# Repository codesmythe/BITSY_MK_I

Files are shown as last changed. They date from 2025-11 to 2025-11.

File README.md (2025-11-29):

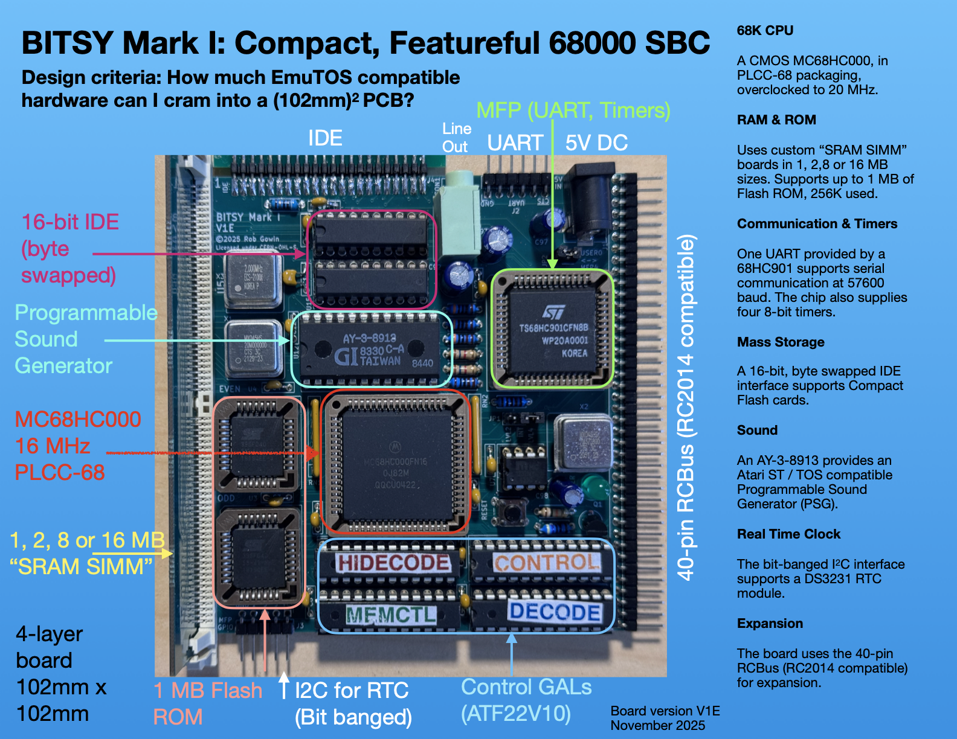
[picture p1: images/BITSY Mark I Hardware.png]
BITSY


This board is designed to run the [EmuTOS](https://emutos.sourceforge.io) operating system. EmuTOS is an open-source variant of the Atari ST TOS operating system.

BITSY Mark I is part of system containing this board, a [XOSERA_RCBUS](https://github.com/codesmythe/XOSERA_RCBUS) board for VGA output, a [KEMOJO](https://github.com/codesmythe/KEMOJO) board for
PS/2 keyboard and mouse input, and an RCBus backplane board such as an [SC147](https://smallcomputercentral.com/rcbus/sc100-series/sc147-modular-backplane-rc2014/). Together, this system can run full GUI EmuTOS with 640x240 graphics in 16 colors.

This SBC can also be used by itself, in EmuTOS command-line mode, using the on-board UART for serial input and output at 57600 baud.

But please do note that it is early days for this system, so there are undiscovered bugs looming. In particular, you may see occasional graphical artifacts in EmuTOS as the driver is debugged.

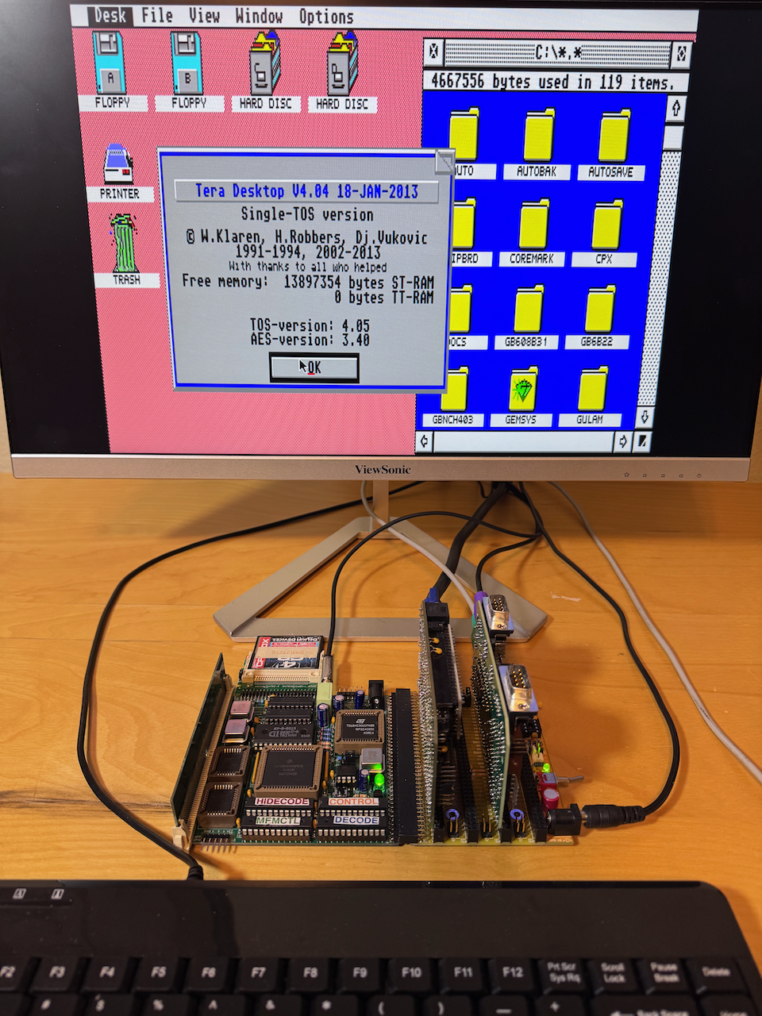
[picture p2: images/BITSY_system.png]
BITSY System
|                      |
| :----------------------------------------------------------: |
| Full BITSY system running [Teradesk](https://github.com/freemint/teradesk) with color icons on EmuTOS. Free memory shows 16 MB SRAM SIMM in use. |

## Table of Contents
* [Hardware Documentation](#hardware-documentation)
  * [Schematic](#schematic)
  * [Connectors](#connectors)
  * [Jumpers](#jumpers)
  * [SRAM Choice](#sram-choice)
  * [Bill of Materials](#bill-of-materials)
* [Firmware Documentation](#firmware-documentation)
   * [ROM: EmuTOS](#rom-emutos)
   * [SPLD Fuse Maps](#spld-fuse-maps)

## Hardware Documentation

### Schematics

This four layer, 102mm x 102mm board was created using [Kicad](https://www.kicad.org) version 8.0. The KiCad files are
available in this repository.

The image below shows the top level schematic page. Click on it to download the full eight page schematic in PDF format.

Schematic

### Connectors

| Reference | Description |
| --- | --- |
| J1 | Barrel jack connection for a 2A, 5V, 2mm power supply. |
| J2 | Six pin male header for connection to a USB-to-serial adapters. Uses the [FTDI Friend](https://www.adafruit.com/product/284) pinout. |
| J3 | Five pin male header for connection to a DS3231 Real Time Clock module. |
| J5 | 40-pin connection to an RCBus 40-pin or 80-pin backplane. |

### Jumpers

| Refence | Picture | Description | Comment |
| --- | --- | --- | --- |
| JP1 | | Connects RCBus /INT (pin 22) to 68K interrupt level 4 (1-2) or level 2 (2-3) | When using BITSY Mark I with the [XOSERA_RCBUS](https://github.com/codesmythe/XOSERA_RCBUS) board, jumper pins 1-2 to use 68K /INT4. |
| JP2 | | When closed, connects RCBus USER1/INT1 (pin 37) to MFP GPIO4. When open, RCBus pin 37 is unconnected. | Close this jumper when using the [KEMOJO](https://github.com/codesmythe/KEMOJO) board for PS/2 keyboard, PS/2 mouse and joystick support. |

### SRAM Choice

Memory for this board is hosted on a custom 72-pin "SRAM SIMM" board. Though SIMMs are conventionally associated with DRAMs, these custom modules present a static RAM (SRAM) interface to the motherboard. Thus they have a demultiplexed address bus and use SRAM control signals such as chip enable, output enable and write enables.

> [!WARNING]
> BITSY_MK_I is **completely incompatible** with conventional DRAM SIMMs.

#### 1 MB SRAM SIMM

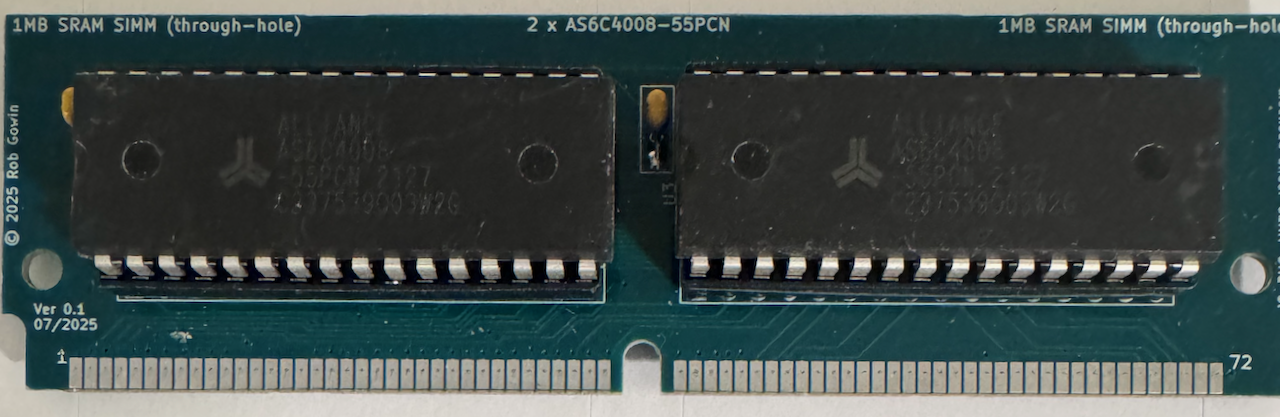
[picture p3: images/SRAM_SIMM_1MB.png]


The 1 MB through hole version is a good choice to start with, as it is inexpensive and easy to solder. Gerbers for the boards are available in this repository. So if you
are ordering a BITSY board from a PCB maker, also order one of these memory modules.

#### 16 MB SRAM SIMM

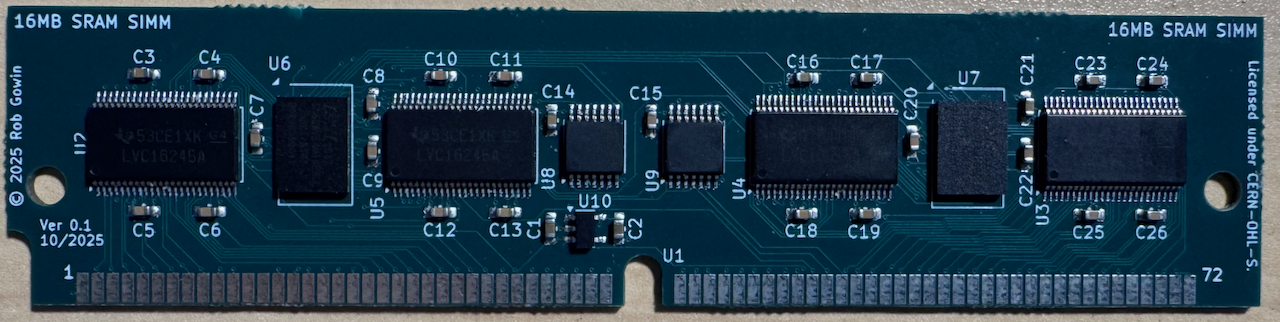
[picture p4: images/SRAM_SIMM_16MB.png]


If you end up using the system regularly, I'd suggest upgrading to a 16 MB "SRAM SIMM" I have created. If interested, please contact me about purchasing a 16 MB module, which run about USD $36 each. Alternatively, you can have JLCPCB assemble them yourself using the design files in [this](http://github.com/codesmythe/SRAM_SIMM_16MB) repository.

### Bill of Materials

[Text file parts list](BITSY_V1E_mouser.txt) for pasting into the [Mouser BOM tool](https://www.mouser.com/Bom/CopyPaste) (login required).

To obtain a BITSY Mark I PCB, download these [Gerbers](https://github.com/codesmythe/BITSY_MK_I/raw/refs/heads/main/BITSY_Mark_I_V1E.zip) for use at your preferred PCB manufacturer. I use JLCPCB.

| Component Type | Reference | Qty  | Description | Part |
| --- | --- | ---- | --- | --- |
| CF Adapter | none | 1 | Compact Flash Male IDE 44pin adapter | eBay or Amazon: search for "Compact Flash Male IDE 44pin adapter" |
| RTC | none | 1 | (optional) DS3231 I2C Real Time Clock module | Amazon: search for "DS3231 rtc module". Get a black one with 5-pin female connector and yellow battery. |
| Capacitor | C1-C4,C7-C12,C14,C15 | 12 | 0.1 uF, MLCC, 5 mm Pitch | Mouser [594-K104K15X7RF5TH5](https://www.mouser.com/ProductDetail/594-K104K15X7RF5TH5) |
| Capacitor | C92,C93 | 2 | Electrolytic Capacitor, Radial, 6.3V 470uF, 6.3D, 2.5P | Mouser [80-ESK477M6R3AE3AA](https://www.mouser.com/ProductDetail/80-ESK477M6R3AE3AA) |
| Capacitor | C94 | 1 | MLCC, Leaded 100pF 50V 5% C0G 5mm | Mouser [594-K101J15C0GF5TH5](https://www.mouser.com/ProductDetail/594-K101J15C0GF5TH5) |
| Capacitor | C97,C98 | 2 | Electrolytic Capacitor, Radial, 16V, 100uF, 5D, 2.5P | Mouser [667-ECA-1CM101I](https://www.mouser.com/ProductDetail/667-ECA-1CM101I) |
| Capacitor | CON1 | 1 | Audio Jack, 3 Poles, Switched TR Poles | Mouser [490-SJ1-3535NG](https://www.mouser.com/ProductDetail/490-SJ1-3535NG) |
| Diode | D1 | 1 | Green LED, through hole, 5 mm pitch | Mouser [859-LTL-307GLC](https://www.mouser.com/ProductDetail/859-LTL-307GLC) |
| Jumper | J1 | 1 | DC Barrel Jack | Mouser [490-PJ-002A](https://www.mouser.com/ProductDetail/490-PJ-002A) |
| Jumper | J2 | 1 | 1x6 right angle pin header | Mouser [737-PH1RB-06-UA](https://www.mouser.com/ProductDetail/737-PH1RB-06-UA) |
| Jumper | J3 | 1 | 1x5 right angle pin header | Mouser [737-PH1RB-05-UA](https://www.mouser.com/ProductDetail/737-PH1RB-05-UA) |
| Jumper | J5 | 1 | 1x40 right angle pin header | Mouser [710-61304011021](https://www.mouser.com/ProductDetail/710-61304011021) |
| Jumper | JP1 | 1 | 1x3 straight pin header | Mouser [200-TSW10307TS](https://www.mouser.com/ProductDetail/200-TSW10307TS) |
| Jumper | JP2 | 1 | 1x2 straight pin header | Mouser [200-TSW10207TS](https://www.mouser.com/ProductDetail/200-TSW10207TS) |
| Transistor | Q1 | 1 | 2N7000  MOSFET in TO92 | Mouser [512-2N7000](https://www.mouser.com/ProductDetail/512-2N7000) |
| Resistor | R2 | 1 | 470 ohm, axial, 1% tolerance, 1/4 W | Mouser [603-MFR-25FTE52-470R](https://www.mouser.com/ProductDetail/603-MFR-25FTE52-470R) |
| Resistor | R3 | 1 | 10K ohm, axial, 1% tolerance, 1/4 W | Mouser [603-MFR-25FTE52-10K](https://www.mouser.com/ProductDetail/603-MFR-25FTE52-10K) |
| Resistor | R84,R85 | 2 | 1K ohm, axial, 1% tolerance, 1/4 W | Mouser [603-MFR-25FTE52-1K](https://www.mouser.com/ProductDetail/603-MFR-25FTE52-1K) |
| Resistor | R86,R87 | 2 | 1600 ohm, axial, 1% tolerance, 1/4 W | Mouser [603-MFR-25FTE52-1K6](https://www.mouser.com/ProductDetail/603-MFR-25FTE52-1K6) |
| Resistor | R88-R90 | 3 | 3K ohm, axial, 1% tolerance, 1/4 W | Mouser [603-MFR-25FTE52-3K](https://www.mouser.com/ProductDetail/603-MFR-25FTE52-3K) |
| Resistor | R97 | 1 | 100 ohm, axial, 1% tolerance, 1/4 W | Mouser [603-MFR-25FBF52-100R](https://www.mouser.com/ProductDetail/603-MFR-25FBF52-100R) |
| Resistor | RN1,RN2 | 2 | 4.7K ohm bussed network, 6 resistors, 7 pins, SIP | Mouser [652-4607X-1LF-4.7K](https://www.mouser.com/ProductDetail/652-4607X-1LF-4.7K) |
| Switch | SW1 | 1 | Push button switch | Mouser [179-TS026655BK160LCR](https://www.mouser.com/ProductDetail/179-TS026655BK160LCR) |
| Integrated Circuit | U1 | 1 | MC68HC000 CPU in PLCC-68, 20 MHz | Ebay: search for "MC68HC000FN20" |
| Integrated Circuit | U2 | 1 | TS68HC901 Multi Function Peripheral (MFP) chip in PLCC-52 | Ebay: search for "TS68HC901CFN8B" |
| Integrated Circuit | U3,U4 | 2 | 512k x 8 Flash ROM in PLCC-32 | Mouser [579-39SF040554CNHET](https://www.mouser.com/ProductDetail/579-39SF040554CNHET) |
| Integrated Circuit | U7 | 1 | MIC1232 CPU Supervisor in 8-pin DIP | Mouser [998-MIC1232NY](https://www.mouser.com/ProductDetail/998-MIC1232NY) |
| Integrated Circuit | U8-U11 | 4 | ATF22V10C-15PU, Simple PLD, 24 I/O in 24-pin DIP | Mouser [556-AF22V10C15PU](https://www.mouser.com/ProductDetail/556-AF22V10C15PU) |
| Integrated Circuit | U12 | 1 | AY-3-8913 Programmable Sound Generator (PSG) in 24-pin wide DIP | Ebay: search for "AY-3-8913" |
| Integrated Circuit | U14,U15 | 2 | 74HCT245 Octal Bus Transceivers in 20-pin DIP | Mouser [595-SN74HCT245N](https://www.mouser.com/ProductDetail/595-SN74HCT245N) |
| Oscillator | X1 | 1 | 16 MHz can oscillator in 8-pin DIP | Mouser [774-MXO45HST-3C-16.0](https://www.mouser.com/ProductDetail/774-MXO45HST-3C-16.0) |
| Oscillator | X2 | 1 | 7.3278 MHz can oscillator in 8-pin DIP | Mouser [774-MXO45HS-3C-7.3](https://www.mouser.com/ProductDetail/774-MXO45HS-3C-7.3) |
| Oscillator | X3 | 1 | 2 MHz can oscillator in 8-pin DIP | Mouser [774-MXO45HS2C2M0000](https://www.mouser.com/ProductDetail/774-MXO45HS2C2M0000) |
| Socket | Socket for U1 | 1 | 68-pin PLCC socket | Mouser [575-682444](https://www.mouser.com/ProductDetail/575-682444) |
| Socket | Socket for U2 | 1 | 52-pin PLCC socket | Mouser [575-945224](https://www.mouser.com/ProductDetail/575-945224) |
| Socket | Socket for U3,U4 | 2 | 32-pin PLCC socket | Mouser [649-54020-32030LF](https://www.mouser.com/ProductDetail/649-54020-32030LF) |
| Socket | Socket U5 | 1 | SIMM Connectors 72 POS SIMM VERT TIN | Mouser [571-5822021-4](https://www.mouser.com/ProductDetail/571-5822021-4) |
| Socket | Socket for U7 | 1 | 8-pin DIP socket | Mouser [737-ICM-308-1-GT-HT](https://www.mouser.com/ProductDetail/737-ICM-308-1-GT-HT) |
| Socket | Socket for U8-U11 | 4 | 24-pin DIP socket | Mouser [737-ICM-324-1-GT-HT](https://www.mouser.com/ProductDetail/737-ICM-324-1-GT-HT) |
| Socket | Socket for U12 | 1 | 24-pin wide DIP socket | Mouser [737-ICM-624-1-GT-HT](https://www.mouser.com/ProductDetail/737-ICM-624-1-GT-HT) |
| Socket | Socket for U14,U15 | 2 | 20-pin DIP socket | Mouser [737-ICM-320-1-GT-HT](https://www.mouser.com/ProductDetail/737-ICM-320-1-GT-HT) |
| Socket | Socket for X1-X3 | 3 | 8-pin oscillator socket | Mouser [535-1108800](https://www.mouser.com/ProductDetail/535-1108800) |

## Firmware Documentation

### ROM: EmuTOS

As mentioned, this board is designed to run EmuTOS. The source code for my fork of EmuTOS to support various 68K single
board computers, including this one, can be found [here](https://github.com/codesmythe/emutos). The version of EmuTOS in the fork is
based on EmuTOS version 1.4.

Two default configurations are provided by the ROM binaries in this repository. Other configurations are
available by compiling EmuTOS from the source code linked above.

#### Configuration: Using serial port command line I/O interface

The first configuraiton uses the UART provided by the MC68901 and runs EmuTOS in "serial console" mode. 
In this configuration, 1 MB of SRAM is supported, which can be provided using two standard 512K 32-pin DIP SRAMs 
like the AS6C4008 mounted on an "SRAM SIMIM" adapter mentioned above. The "EmuCON" part of EmuTOS provides a command line interface. Here are the even and odd ROM binaries for this configuration:

| ROM  | Size | File | 
| ---- | --- | ---- |
| Even | 512KB  | [bitsy_v1_sercon_1mb_20251123.even.bin](https://github.com/codesmythe/BITSY_MK_I/raw/refs/heads/main/ROMS/bitsy_v1_sercon_1mb_20251123.even.bin) | 
| Odd  | 512KB  | [bitsy_v1_sercon_1mb_20251123.odd.bin](https://github.com/codesmythe/BITSY_MK_I/raw/refs/heads/main/ROMS/bitsy_v1_sercon_1mb_20251123.odd.bin) | 

#### Configuration: Using VGA and PS/2 support to run EmuTOS GUI (GEM)

The second configuration runs EmuTOS in full GUI (GEM) mode and requires the use of the 
[XOSERA_RCBUS](https://github.com/codesmythe/XOSERA_RCBUS) and [KEMOJO](https://github.com/codesmythe/KEMOJO) boards to provide VGA output and PS/2 keyboard and mouse input. In this configuration, at least 4MB is suggested so I recommend using the 16 MB "SRAM SIMM" module described above. It is possible to run GEM mode in 1 MB of RAM, but for you now you will have configure EmuTOS and compile it from source. Here are the even and odd ROM binaries for the 14 MB configuration:

| ROM  | Size | File | 
| ---- | --- | ---- |
| Even | 512KB  | [bitsy_v1_gem_14mb_20251123.even.bin](https://github.com/codesmythe/BITSY_MK_I/raw/refs/heads/main/ROMS/bitsy_v1_gem_14mb_20251123.even.bin) |
| Odd  | 512KB  | [bitsy_v1_gem_14mb_20251123.odd.bin](https://github.com/codesmythe/BITSY_MK_I/raw/refs/heads/main/ROMS/bitsy_v1_gem_14mb_20251123.odd.bin) |

#### Memory Map

| Address Range | Use  |
| ---|---|
| 00_0000 to (0F_FFFF or DF_FFFF) | 1 MB or 14 MB RAM |
| E0_0000 to EF_FFFF | 1 MB ROM |
| F0_0000 to F0_003F | IDE (mirrored every 64 bytes in the 4K byte range from F0_0000 to F0_0FFF.) |
| FF_0000 to FF_FFFF | 64K RC2014 IO (IOREQ). Includes the on-board PSG and MFP. |

#### I/O Map

These addresses (and the IDE addresses above) are the same as the Atari ST for software compatibility.

| Address Range | Use | 
|---|---|
| FF_FA01 to FF_FA2F | MFP (odd byte lane) mirrored every 48 bytes in the 256 byte range from FF_FA00 to FA_FAFF.) |
| FF_8800 to FF_8803 | PSG (even byte lane) mirrored every  4 bytes in the 256 byte range from FF_8800 to FF_88FF.) | 
| FF_0191 to FF_01A1 | TL16C550 UART on KEMOJO board (odd byte lane), if using default setting of 0xC8 on that board. |
| FF_81c1 to FF_81E1 | Xosera registers, if using default setting of 0xE0 on that board. |

### SPLD Fuse Maps

BITSY Mark I uses four ATF22V10/GAL22V10 SPLDs (U8 - U11) for address decode and various other control logic. The SPLD fuse maps (JED files) can be downloaded via the links in the table below. The SPLDs are implemented using Flash/EEPROM technology and can be programmed by commonly available EPROM programmers, such as MiniPro TL866 II+ or newer. The source code (PLD) files  are also provided in the repository. If needed, they can be modified. Use [GALasm](https://github.com/daveho/GALasm)  to compile PLD files to JED fuse maps.

Note that there are separate fuse files for U9/HIDECODE depending on whether you are using 1 MB or 14 MB SRAM.

| Reference  | Source File | JED File | Functions |
| --- | --- | --- | --- |
| U8 | [MEMCTL.PLD](MEMCTL.PLD) | [MEMCTL.jed](https://github.com/codesmythe/BITSY_MK_I/raw/refs/heads/main/MEMCTL.jed) | Interrupt control, RCBus interface |
| U9 (1 MB)  | [HIDECODE.PLD](HIDECODE.PLD) | [HIDECODE.jed](https://github.com/codesmythe/BITSY_MK_I/raw/refs/heads/main/HIDECODE.jed) | Decode high part of address bus for 1 MB SRAM  |
| U9 (16 MB) | [HIDECODE_16MB.PLD](HIDECODE_16MB.PLD) | [HIDECODE_16MB.jed](https://github.com/codesmythe/BITSY_MK_I/raw/refs/heads/main/HIDECODE_16MB.jed) | Decode high part of address bus for 14 MB SRAM |
| U10 | [CONTROL.PLD](CONTROL.PLD) | [CONTROL.jed](https://github.com/codesmythe/BITSY_MK_I/raw/refs/heads/main/CONTROL.jed) | Wait states, DTACK generation, IDE interface |
| U11 | [DECODE.PLD](DECODE.PLD) | [DECODE.jed](https://github.com/codesmythe/BITSY_MK_I/raw/refs/heads/main/DECODE.jed) | Decode low part of address bus |

### Acknowledgements

When I designed this board, I took ideas and inspiration from these projects:

- Bill Shen's [Tiny68K](https://www.retrobrewcomputers.org/doku.php?id=boards:sbc:tiny68k) board.

- John Coffmans's [Mini-68K](https://www.retrobrewcomputers.org/doku.php?id=boards:ecb:mini-68k:start) ECB board.

- Clements, Alan. [*Microprocessor Systems Design: 68000 Hardware, Software and Interfacing, Third Edition*](https://archive.org/details/microprocessor-systems-design-alan-clements-9780534948221)
 PWS Publishing Company, 1997.

- [Atari ST schematics](https://archive.org/details/Atari_520ST_Schematic_1985/mode/1up)

- Various [Motorola Application Notes](http://www.bitsavers.org/components/motorola/_appNotes/) from back in the day.

The sound output circuit is borrowed from https://hw.speccy.cz/melodik2.html by way of https://github.com/electrified/rc2014-ym2149/blob/main/README.md

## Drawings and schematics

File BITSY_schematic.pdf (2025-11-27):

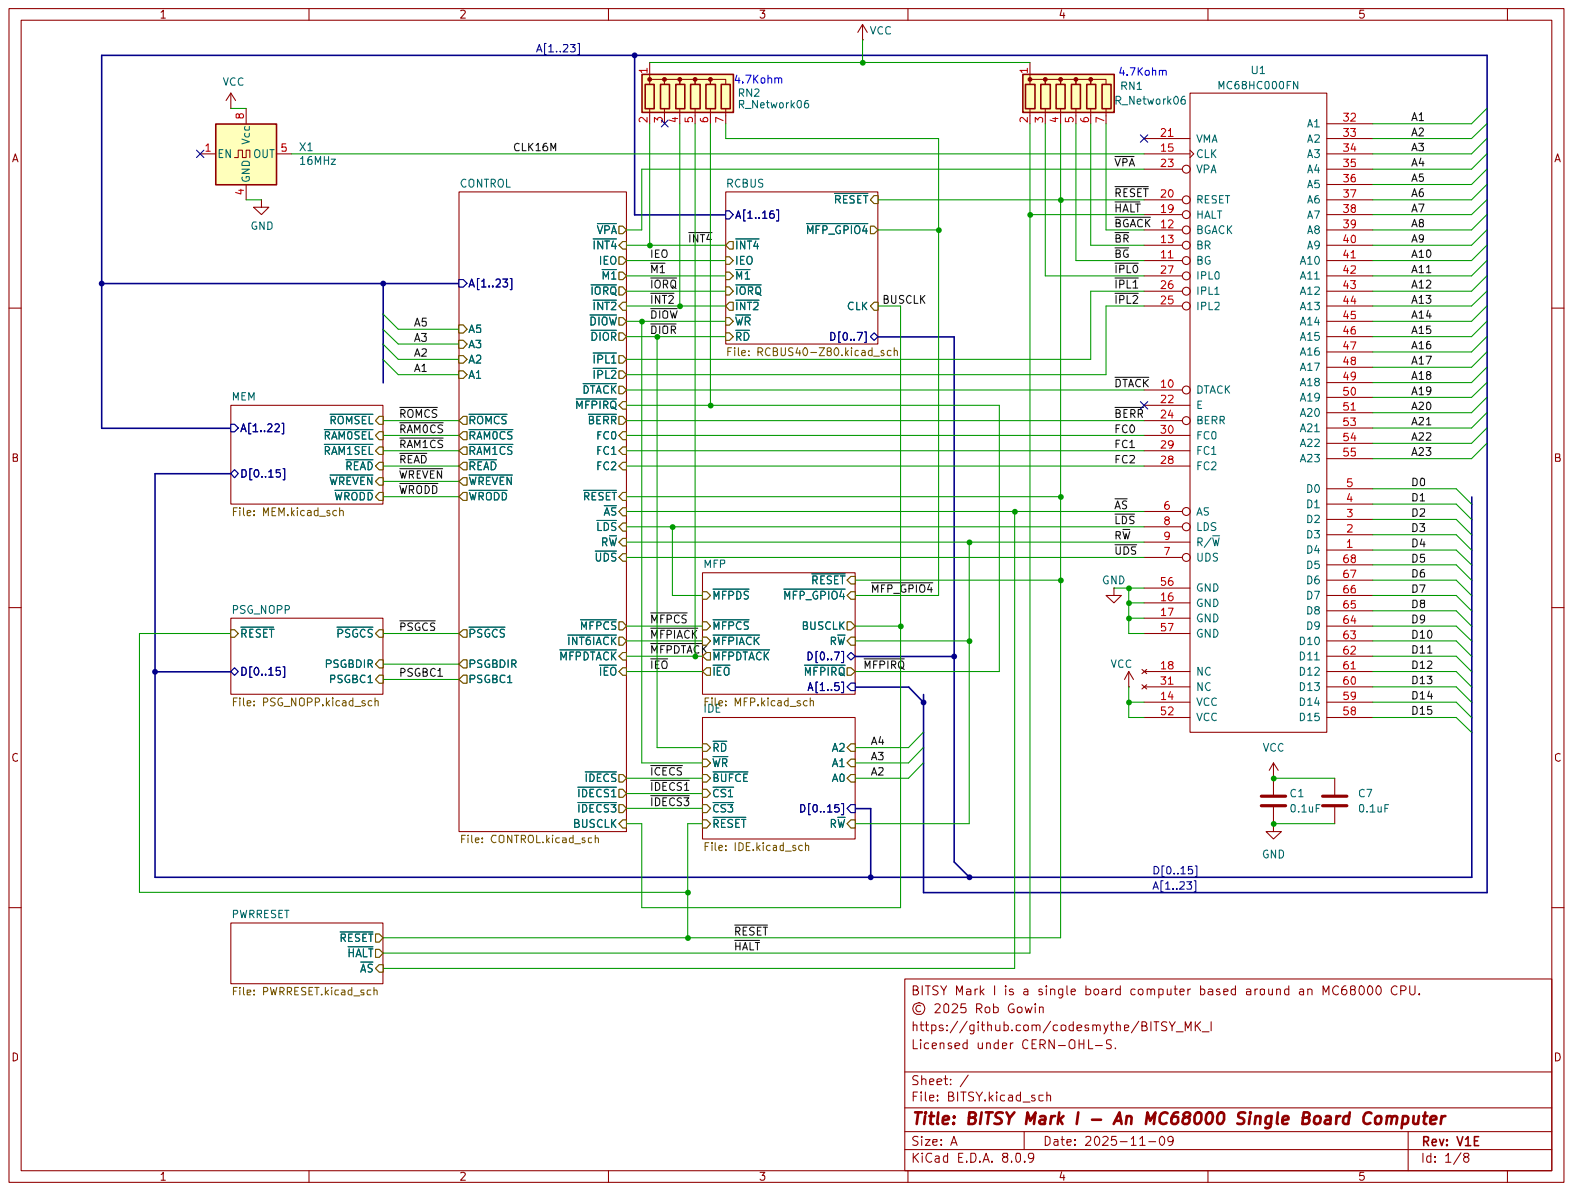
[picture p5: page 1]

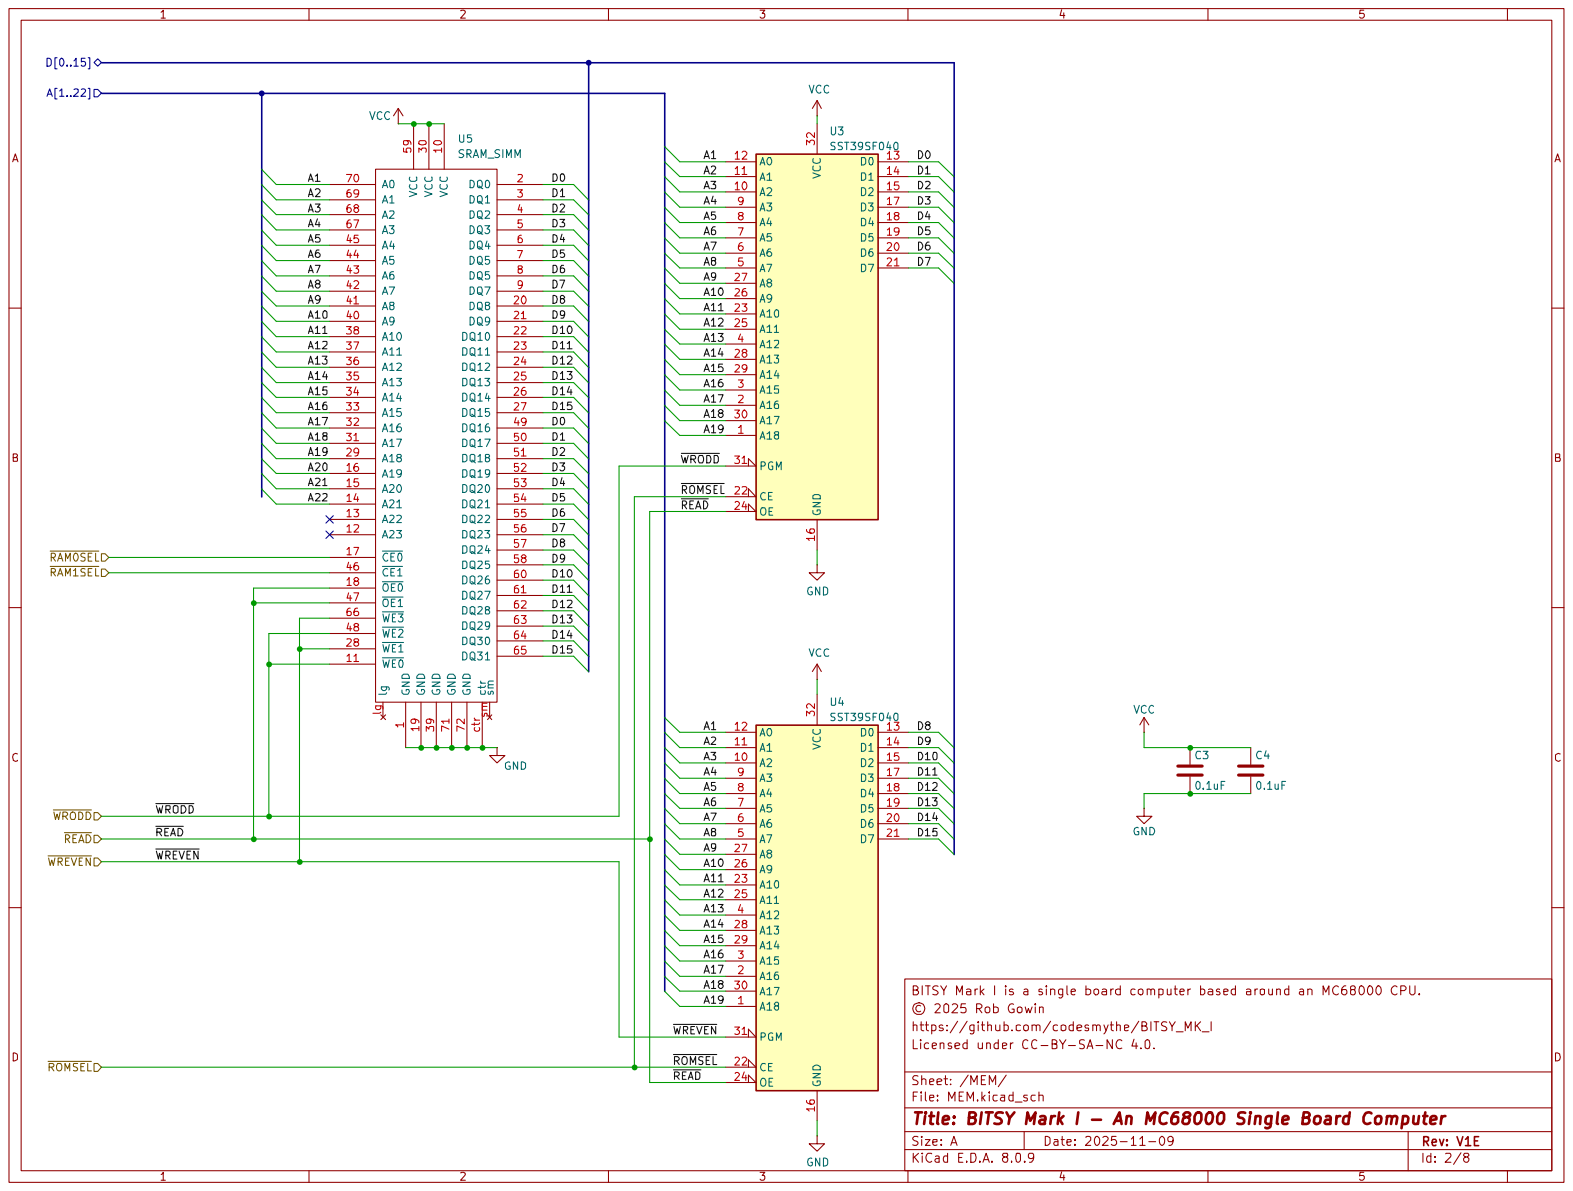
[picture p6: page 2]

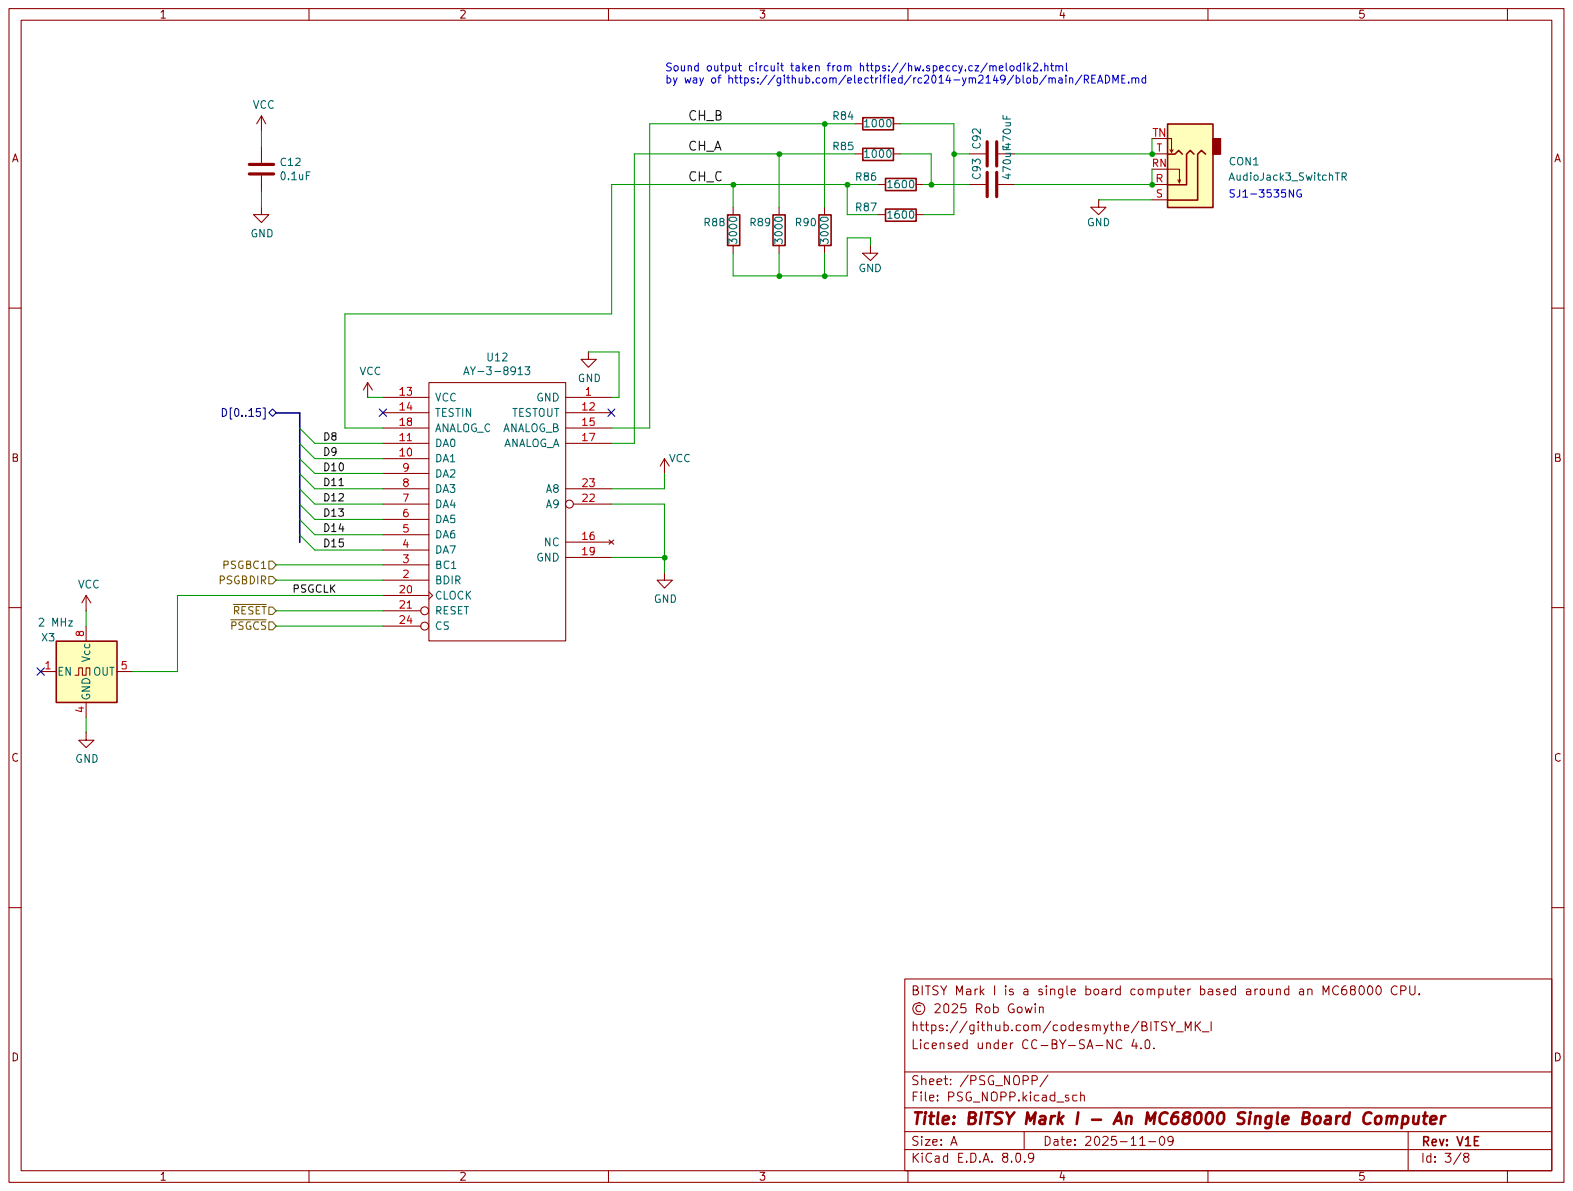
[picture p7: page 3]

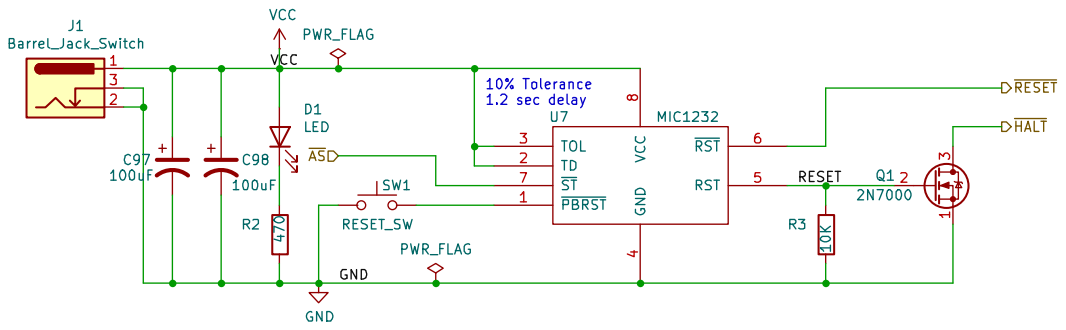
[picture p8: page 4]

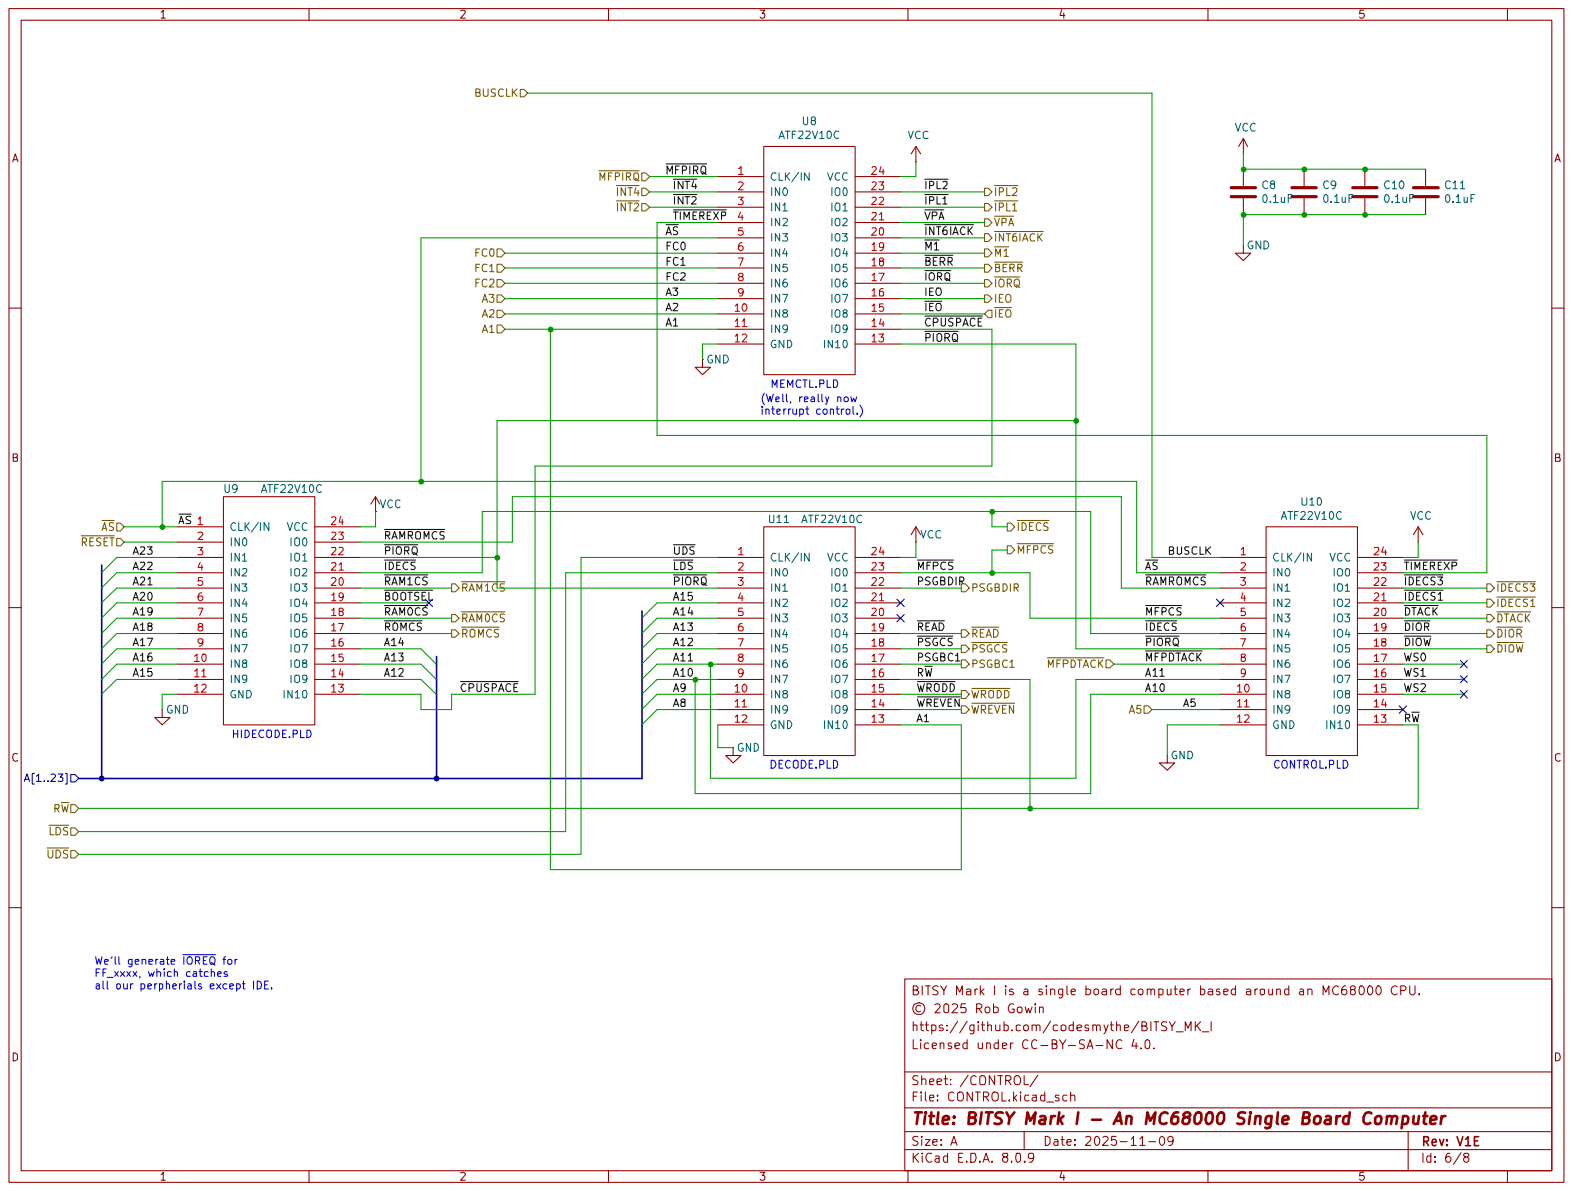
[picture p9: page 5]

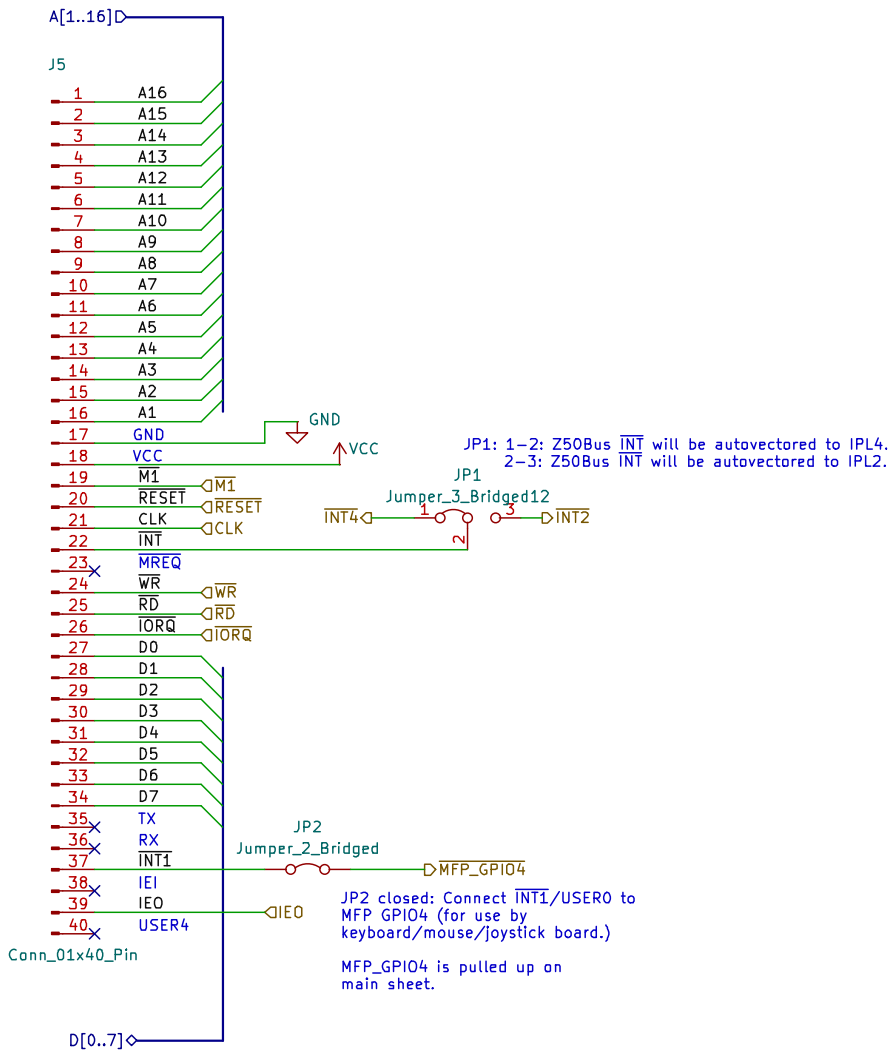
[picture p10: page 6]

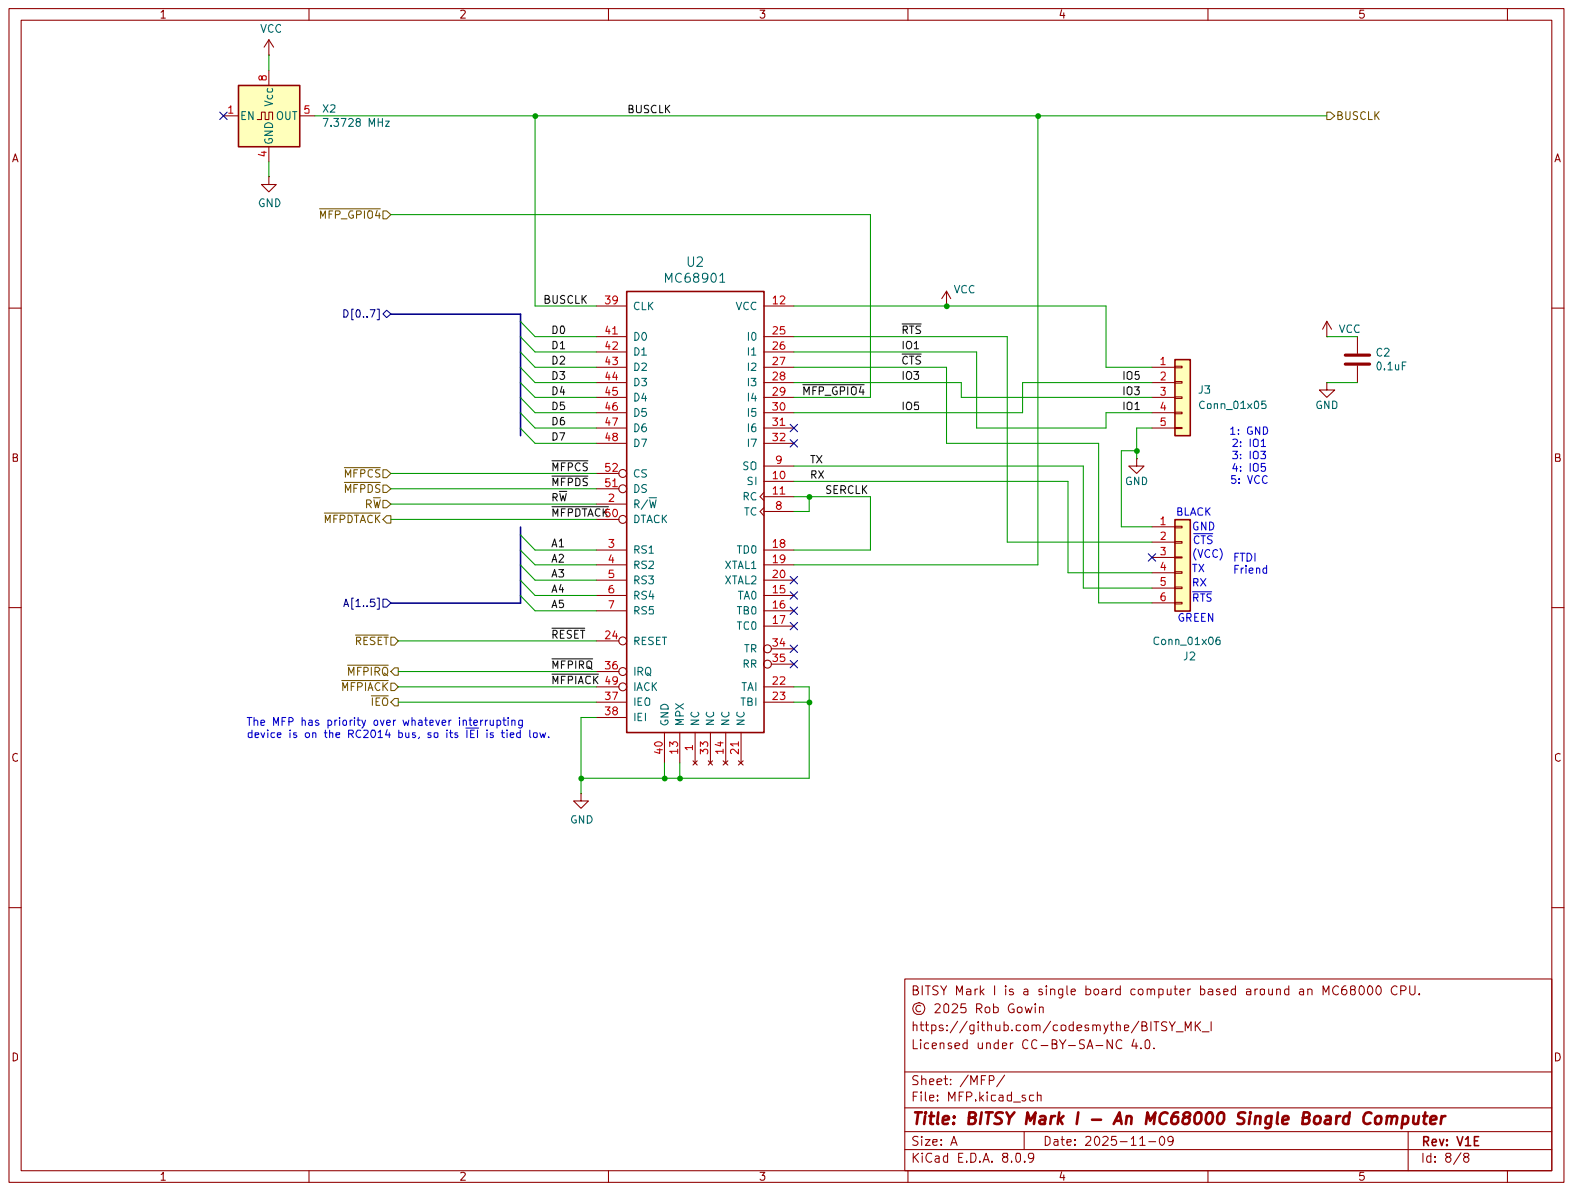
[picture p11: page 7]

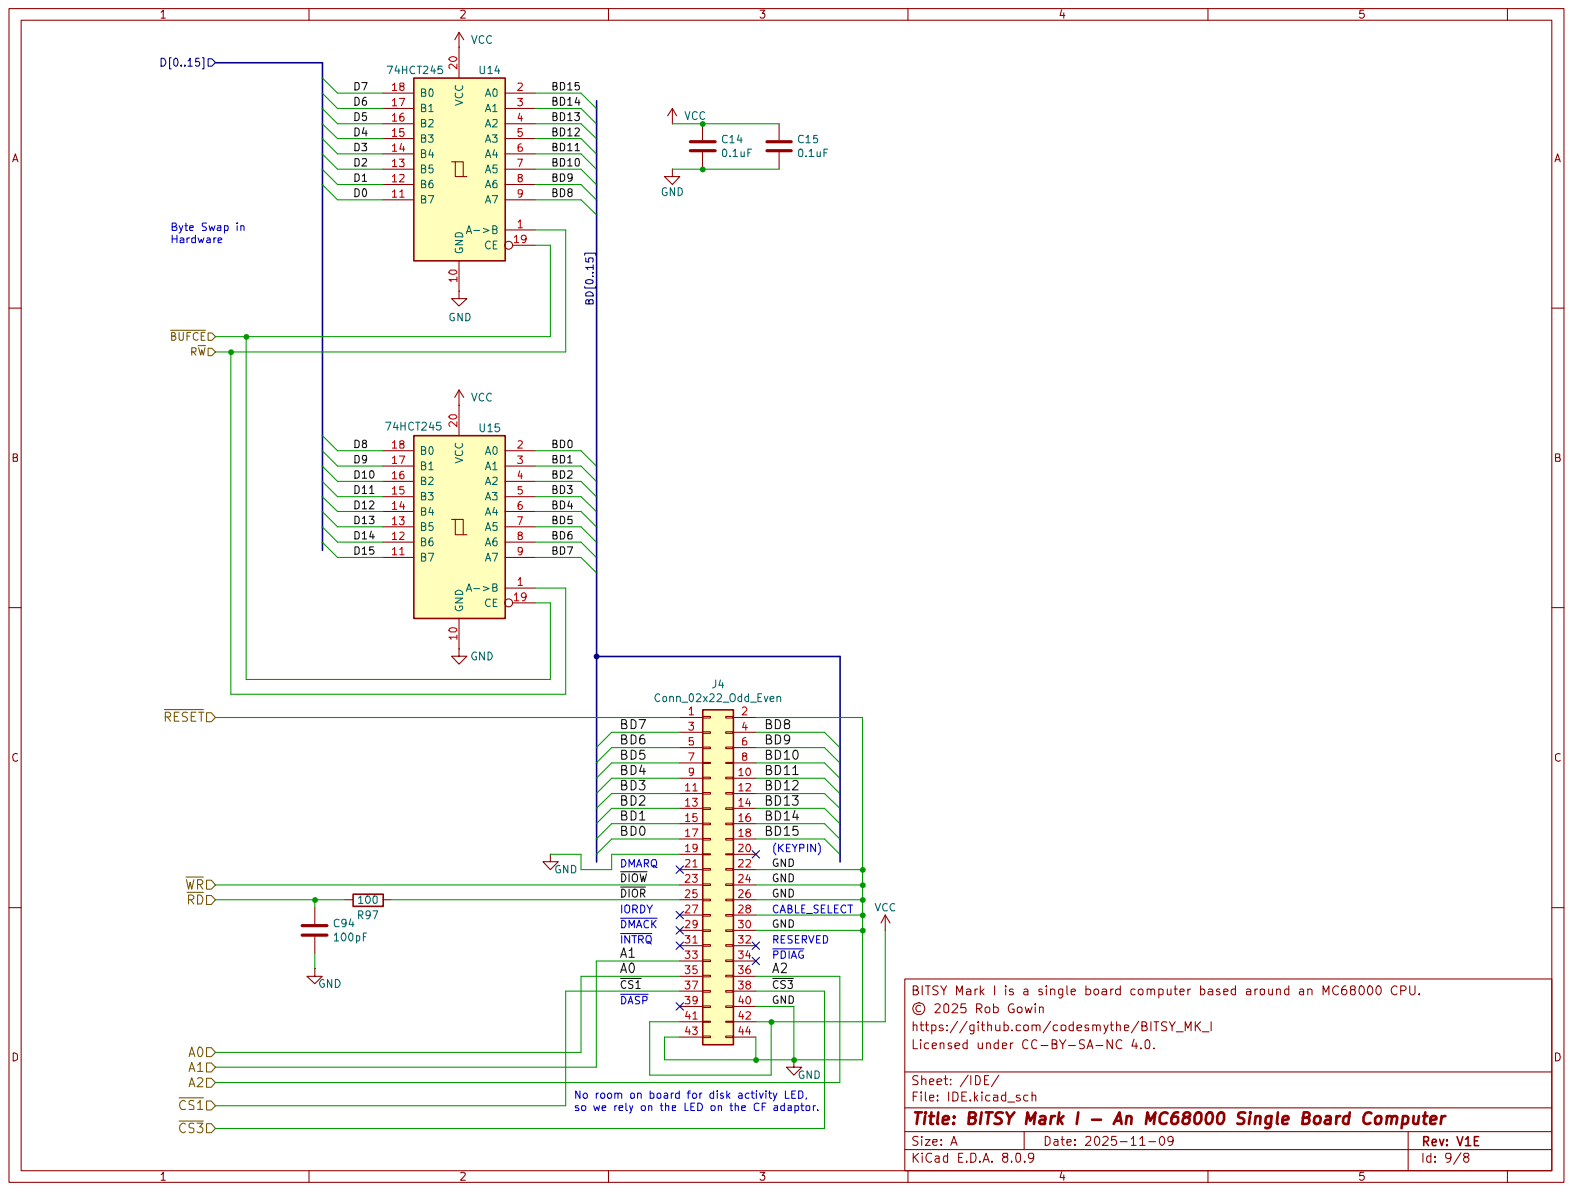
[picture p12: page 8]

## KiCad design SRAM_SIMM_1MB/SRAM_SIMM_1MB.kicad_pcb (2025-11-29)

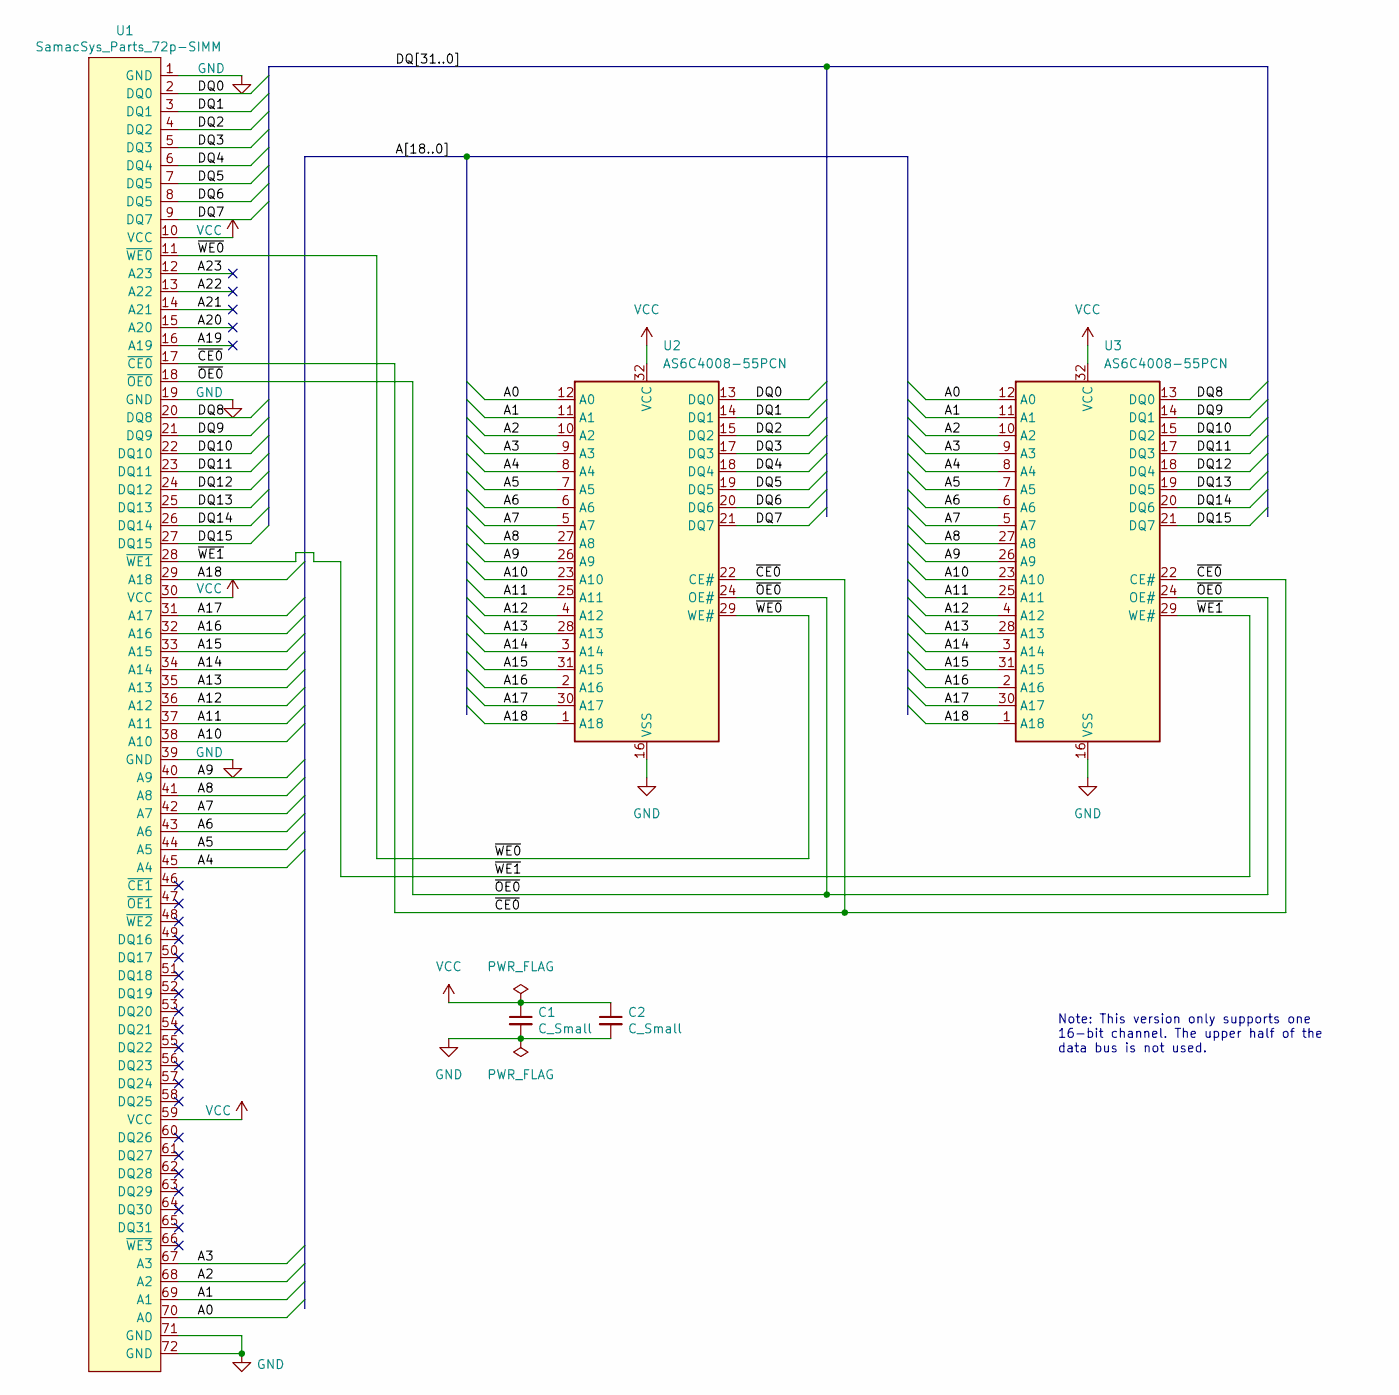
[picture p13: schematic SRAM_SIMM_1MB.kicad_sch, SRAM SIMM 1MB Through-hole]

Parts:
C1, C2: C_Small; C_Rect_L7.0mm_W2.5mm_P5.00mm; MouserPN 594-K104K15X7RF5TH5; LCSC C2167231
U1: SamacSys_Parts_72p-SIMM; 72p-SIMM; MouserPN 571-5822021-4; DigiKeyPN A114049-ND
U2, U3: AS6C4008-55PCN; DIP-32_W15.24mm_Socket_LongPads; MouserPN 913-AS6C4008-55PCN; LCSC C1350141

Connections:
/A0: U1.70 (A0), U2.12 (A0), U3.12 (A0)
/A1: U1.69 (A1), U2.11 (A1), U3.11 (A1)
/A2: U1.68 (A2), U2.10 (A2), U3.10 (A2)
/A3: U1.67 (A3), U2.9 (A3), U3.9 (A3)
/A4: U1.45 (A4), U2.8 (A4), U3.8 (A4)
/A5: U1.44 (A5), U2.7 (A5), U3.7 (A5)
/A6: U1.43 (A6), U2.6 (A6), U3.6 (A6)
/A7: U1.42 (A7), U2.5 (A7), U3.5 (A7)
/A8: U1.41 (A8), U2.27 (A8), U3.27 (A8)
/A9: U1.40 (A9), U2.26 (A9), U3.26 (A9)
/A10: U1.38 (A10), U2.23 (A10), U3.23 (A10)
/A11: U1.37 (A11), U2.25 (A11), U3.25 (A11)
/A12: U1.36 (A12), U2.4 (A12), U3.4 (A12)
/A13: U1.35 (A13), U2.28 (A13), U3.28 (A13)
/A14: U1.34 (A14), U2.3 (A14), U3.3 (A14)
/A15: U1.33 (A15), U2.31 (A15), U3.31 (A15)
/A16: U1.32 (A16), U2.2 (A16), U3.2 (A16)
/A17: U1.31 (A17), U2.30 (A17), U3.30 (A17)
/A18: U1.29 (A18), U2.1 (A18), U3.1 (A18)
/A19: U1.16 (A19)
/A19_1: U1.16 (A19)
/A20: U1.15 (A20)
/A20_1: U1.15 (A20)
/A21: U1.14 (A21)
/A21_1: U1.14 (A21)
/A22: U1.13 (A22)
/A22_1: U1.13 (A22)
/A23: U1.12 (A23)
/A23_1: U1.12 (A23)
/DQ0: U1.2 (DQ0), U2.13 (DQ0)
/DQ1: U1.3 (DQ1), U2.14 (DQ1)
/DQ2: U1.4 (DQ2), U2.15 (DQ2)
/DQ3: U1.5 (DQ3), U2.17 (DQ3)
/DQ4: U1.6 (DQ4), U2.18 (DQ4)
/DQ5: U1.7 (DQ5), U2.19 (DQ5)
/DQ6: U1.8 (DQ5), U2.20 (DQ6)
/DQ7: U1.9 (DQ7), U2.21 (DQ7)
/DQ8: U1.20 (DQ8), U3.13 (DQ0)
/DQ9: U1.21 (DQ9), U3.14 (DQ1)
/DQ10: U1.22 (DQ10), U3.15 (DQ2)
/DQ11: U1.23 (DQ11), U3.17 (DQ3)
/DQ12: U1.24 (DQ12), U3.18 (DQ4)
/DQ13: U1.25 (DQ13), U3.19 (DQ5)
/DQ14: U1.26 (DQ14), U3.20 (DQ6)
/DQ15: U1.27 (DQ15), U3.21 (DQ7)
/~CE0: U1.17 (~CE0), U2.22 (CE#), U3.22 (CE#)
/~OE0: U1.18 (~OE0), U2.24 (OE#), U3.24 (OE#)
/~WE0: U1.11 (~WE0), U2.29 (WE#)
/~WE1: U1.28 (~WE1), U3.29 (WE#)
GND: C1.2, C2.2, U1.1 (GND), U1.19 (GND), U1.39 (GND), U1.71 (GND), U1.72 (GND), U2.16 (VSS), U3.16 (VSS)
VCC: C1.1, C2.1, U1.10 (VCC), U1.30 (VCC), U1.59 (VCC), U2.32 (VCC), U3.32 (VCC)

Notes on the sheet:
Note: This version only supports one 16-bit channel. The upper half of the data bus is not used.

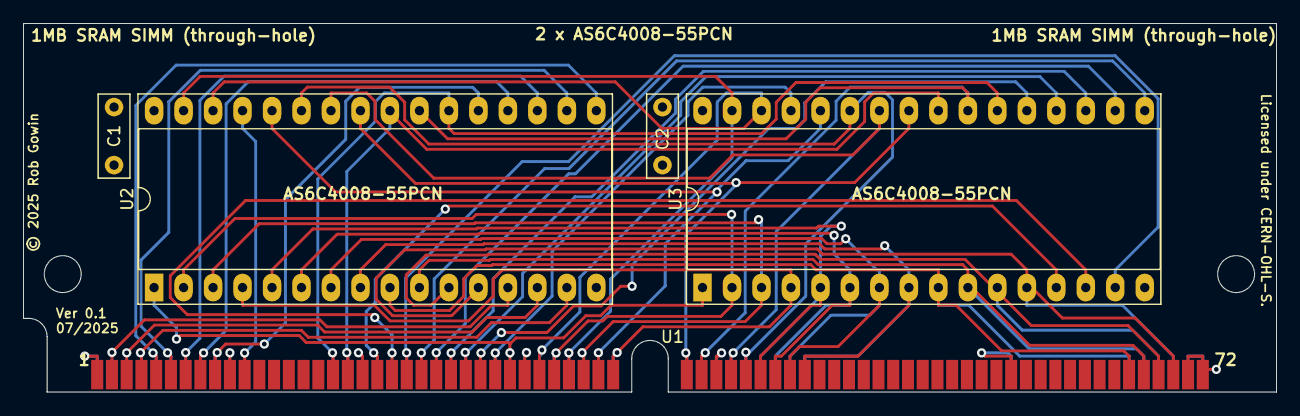
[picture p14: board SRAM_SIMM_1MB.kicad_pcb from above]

Board: 4 copper layers, 107.9 x 31.8 mm, 5 parts (0 on the bottom side), 41 nets.

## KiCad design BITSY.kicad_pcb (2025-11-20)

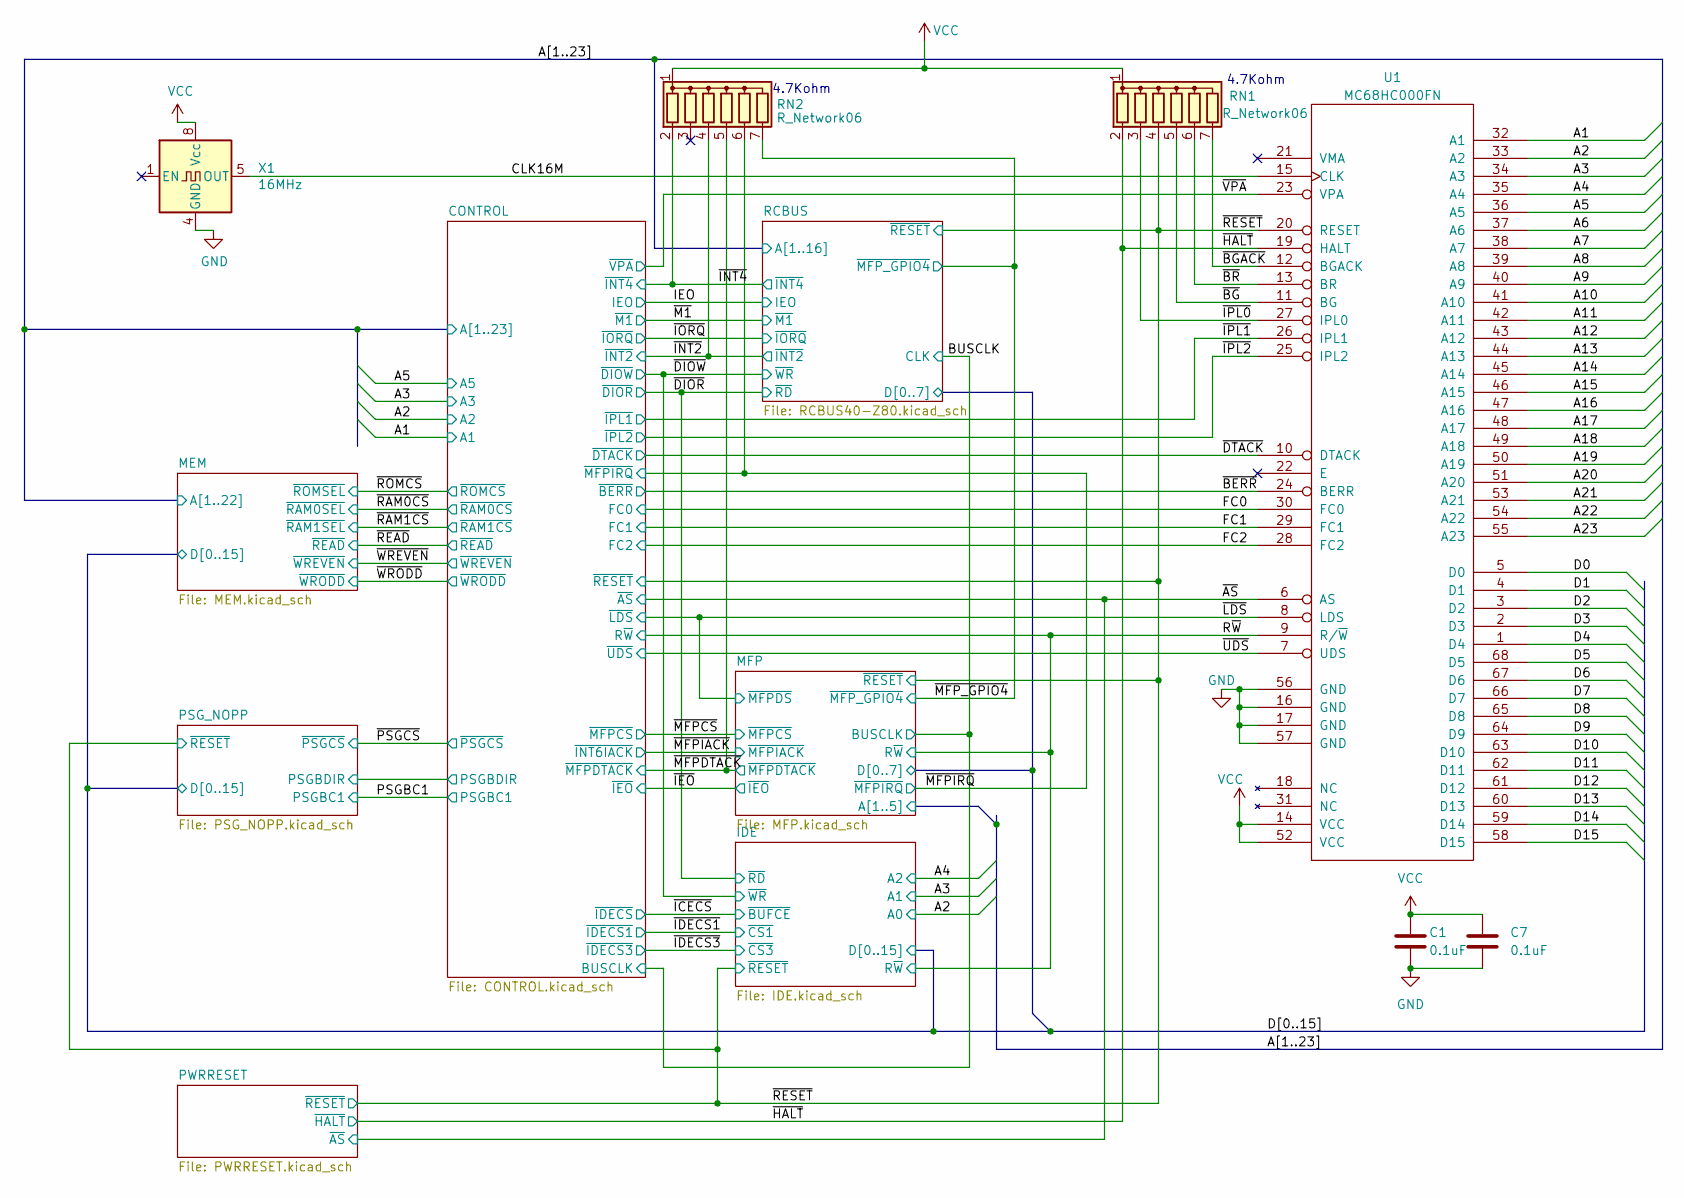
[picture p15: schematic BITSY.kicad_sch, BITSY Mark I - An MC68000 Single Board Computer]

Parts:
C1, C7: 0.1uF; C_Rect_L7.0mm_W2.0mm_P5.00mm; PartNum00 594-K104K15X7RF5TH5
RN1, RN2: R_Network06; R_Array_SIP7; PartNum00 652-4607X-1LF-4.7K
U1: MC68HC000FN; PLCC-68_THT-Socket; PartNum00 MC68HC000FN20
X1: 16MHz; Oscillator_DIP-8; PartNum00 774-MXO45HST-3C-16.0

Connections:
/A1: U1.32 (A1); also elsewhere on the board
/A2: U1.33 (A2); also elsewhere on the board
/A3: U1.34 (A3); also elsewhere on the board
/A4: U1.35 (A4); also elsewhere on the board
/A5: U1.36 (A5); also elsewhere on the board
/A6: U1.37 (A6); also elsewhere on the board
/A7: U1.38 (A7); also elsewhere on the board
/A8: U1.39 (A8); also elsewhere on the board
/A9: U1.40 (A9); also elsewhere on the board
/A10: U1.41 (A10); also elsewhere on the board
/A11: U1.42 (A11); also elsewhere on the board
/A12: U1.43 (A12); also elsewhere on the board
/A13: U1.44 (A13); also elsewhere on the board
/A14: U1.45 (A14); also elsewhere on the board
/A15: U1.46 (A15); also elsewhere on the board
/A16: U1.47 (A16); also elsewhere on the board
/A17: U1.48 (A17); also elsewhere on the board
/A18: U1.49 (A18); also elsewhere on the board
/A19: U1.50 (A19); also elsewhere on the board
/A20: U1.51 (A20); also elsewhere on the board
/A21: U1.53 (A21); also elsewhere on the board
/A22: U1.54 (A22); also elsewhere on the board
/A23: U1.55 (A23); also elsewhere on the board
/CLK16M: U1.15 (CLK), X1.5 (OUT)
/D0: U1.5 (D0); also elsewhere on the board
/D1: U1.4 (D1); also elsewhere on the board
/D2: U1.3 (D2); also elsewhere on the board
/D3: U1.2 (D3); also elsewhere on the board
/D4: U1.1 (D4); also elsewhere on the board
/D5: U1.68 (D5); also elsewhere on the board
/D6: U1.67 (D6); also elsewhere on the board
/D7: U1.66 (D7); also elsewhere on the board
/D8: U1.65 (D8); also elsewhere on the board
/D9: U1.64 (D9); also elsewhere on the board
/D10: U1.63 (D10); also elsewhere on the board
/D11: U1.62 (D11); also elsewhere on the board
/D12: U1.61 (D12); also elsewhere on the board
/D13: U1.60 (D13); also elsewhere on the board
/D14: U1.59 (D14); also elsewhere on the board
/D15: U1.58 (D15); also elsewhere on the board
/FC0: U1.30 (FC0); also elsewhere on the board
/FC1: U1.29 (FC1); also elsewhere on the board
/FC2: U1.28 (FC2); also elsewhere on the board
/R~W: U1.9 (R/~W); also elsewhere on the board
/~AS: U1.6 (AS); also elsewhere on the board
/~BERR: U1.24 (BERR); also elsewhere on the board
/~BGACK: RN1.7 (R6), U1.12 (BGACK)
/~BG: RN1.5 (R4), U1.11 (BG)
/~BR: RN1.6 (R5), U1.13 (BR)
/~DTACK: U1.10 (DTACK); also elsewhere on the board
/~HALT: RN1.2 (R1), U1.19 (HALT); also elsewhere on the board
/~INT2: RN2.4 (R3); also elsewhere on the board
/~INT4: RN2.2 (R1); also elsewhere on the board
/~IPL0: RN1.3 (R2), U1.27 (IPL0)
/~IPL1: U1.26 (IPL1); also elsewhere on the board
/~IPL2: U1.25 (IPL2); also elsewhere on the board
/~LDS: U1.8 (LDS); also elsewhere on the board
/~MFPDTACK: RN2.5 (R4); also elsewhere on the board
/~MFPIRQ: RN2.6 (R5); also elsewhere on the board
/~MFP_GPIO4: RN2.7 (R6); also elsewhere on the board
/~RESET: RN1.4 (R3), U1.20 (RESET); also elsewhere on the board
/~UDS: U1.7 (UDS); also elsewhere on the board
/~VPA: U1.23 (VPA); also elsewhere on the board
GND: C1.2, C7.2, U1.16 (GND), U1.17 (GND), U1.56 (GND), U1.57 (GND), X1.4 (GND); also elsewhere on the board
VCC: C1.1, C7.1, RN1.1 (common), RN2.1 (common), U1.14 (VCC), U1.52 (VCC), X1.8 (Vcc); also elsewhere on the board

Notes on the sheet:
4.7Kohm

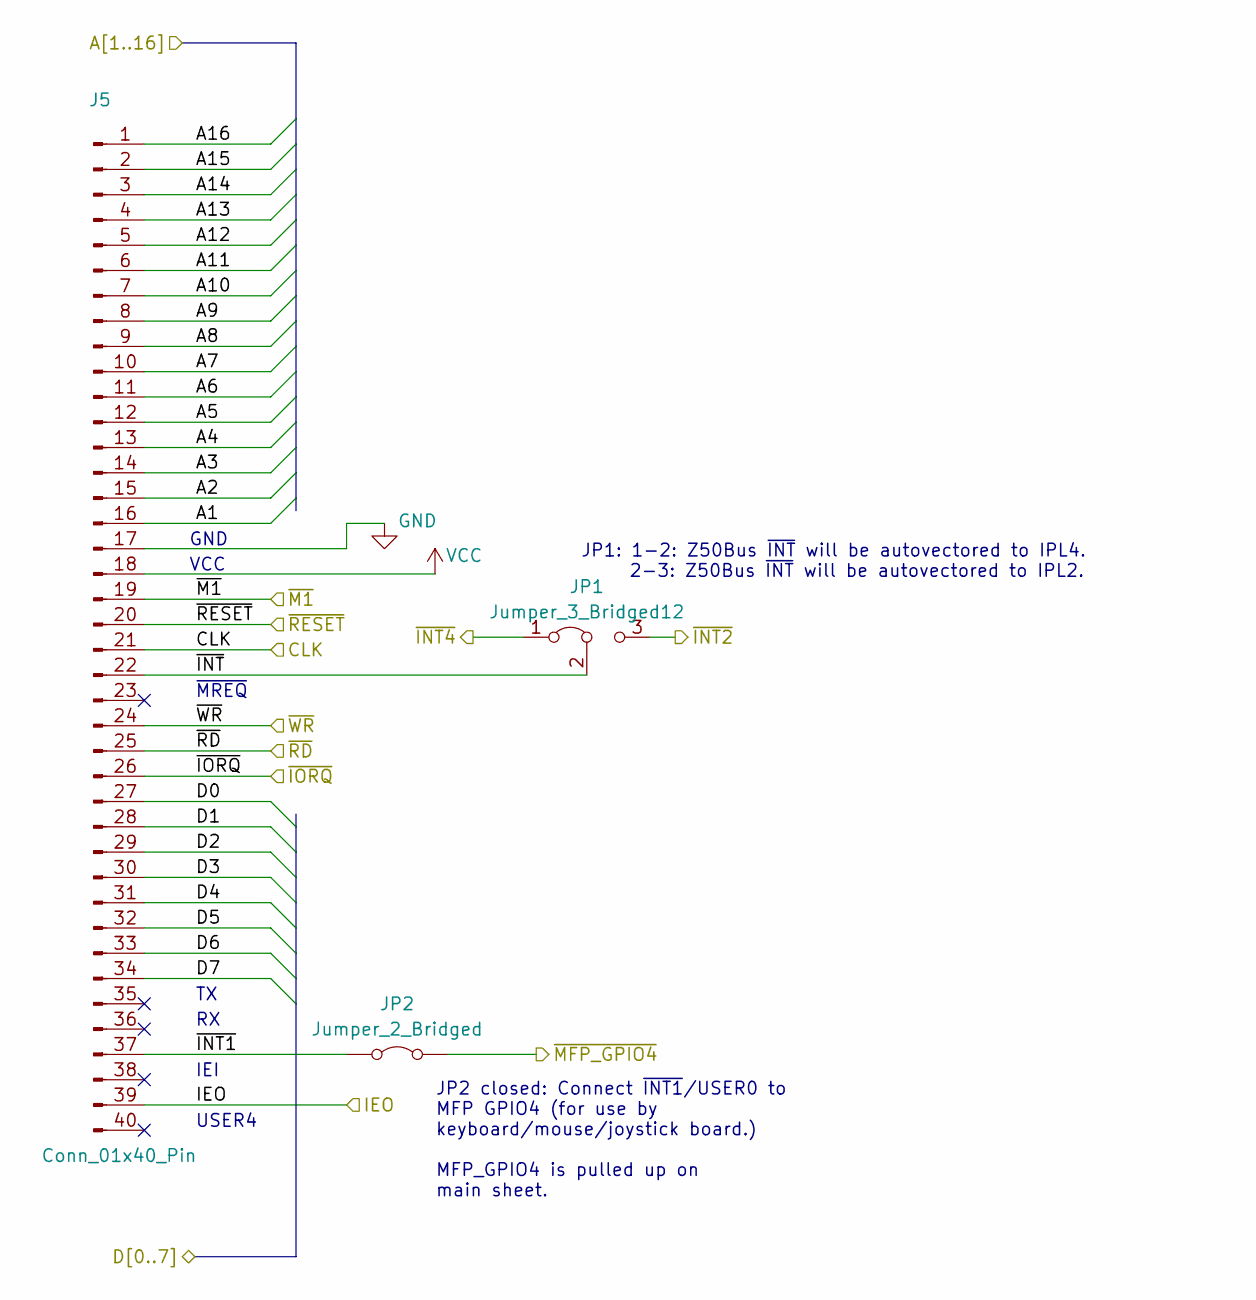
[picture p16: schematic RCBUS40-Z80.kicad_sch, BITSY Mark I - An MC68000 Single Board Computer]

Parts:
J5: Conn_01x40_Pin; PinHeader_1x40_P2.54mm_Vertical; PartNum00 710-61304011021
JP1: Jumper_3_Bridged12; PinHeader_1x03_P2.54mm_Vertical; PartNum00 200-TSW10307TS
JP2: Jumper_2_Bridged; PinHeader_1x02_P2.54mm_Vertical; PartNum00 200-TSW10207TS

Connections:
/A1: J5.16; also elsewhere on the board
/A2: J5.15; also elsewhere on the board
/A3: J5.14; also elsewhere on the board
/A4: J5.13; also elsewhere on the board
/A5: J5.12; also elsewhere on the board
/A6: J5.11; also elsewhere on the board
/A7: J5.10; also elsewhere on the board
/A8: J5.9; also elsewhere on the board
/A9: J5.8; also elsewhere on the board
/A10: J5.7; also elsewhere on the board
/A11: J5.6; also elsewhere on the board
/A12: J5.5; also elsewhere on the board
/A13: J5.4; also elsewhere on the board
/A14: J5.3; also elsewhere on the board
/A15: J5.2; also elsewhere on the board
/A16: J5.1; also elsewhere on the board
/BUSCLK: J5.21; also elsewhere on the board
/D0: J5.27; also elsewhere on the board
/D1: J5.28; also elsewhere on the board
/D2: J5.29; also elsewhere on the board
/D3: J5.30; also elsewhere on the board
/D4: J5.31; also elsewhere on the board
/D5: J5.32; also elsewhere on the board
/D6: J5.33; also elsewhere on the board
/D7: J5.34; also elsewhere on the board
/IEO: J5.39; also elsewhere on the board
/RCBUS/~INT1: J5.37, JP2.1 (A)
/RCBUS/~INT: J5.22, JP1.2 (C)
/~DIOR: J5.25; also elsewhere on the board
/~DIOW: J5.24; also elsewhere on the board
/~INT2: JP1.3 (B); also elsewhere on the board
/~INT4: JP1.1 (A); also elsewhere on the board
/~IORQ: J5.26; also elsewhere on the board
/~M1: J5.19; also elsewhere on the board
/~MFP_GPIO4: JP2.2 (B); also elsewhere on the board
/~RESET: J5.20; also elsewhere on the board
GND: J5.17; also elsewhere on the board
VCC: J5.18; also elsewhere on the board

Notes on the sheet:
VCC
JP2 closed: Connect ~{INT1}/USER0 to MFP GPIO4 (for use by keyboard/mouse/joystick board.) MFP_GPIO4 is pulled up on main sheet.
~{MREQ}
IEI
JP1: 1-2: Z50Bus ~{INT} will be autovectored to IPL4. 2-3: Z50Bus ~{INT} will be autovectored to IPL2.
GND
USER4

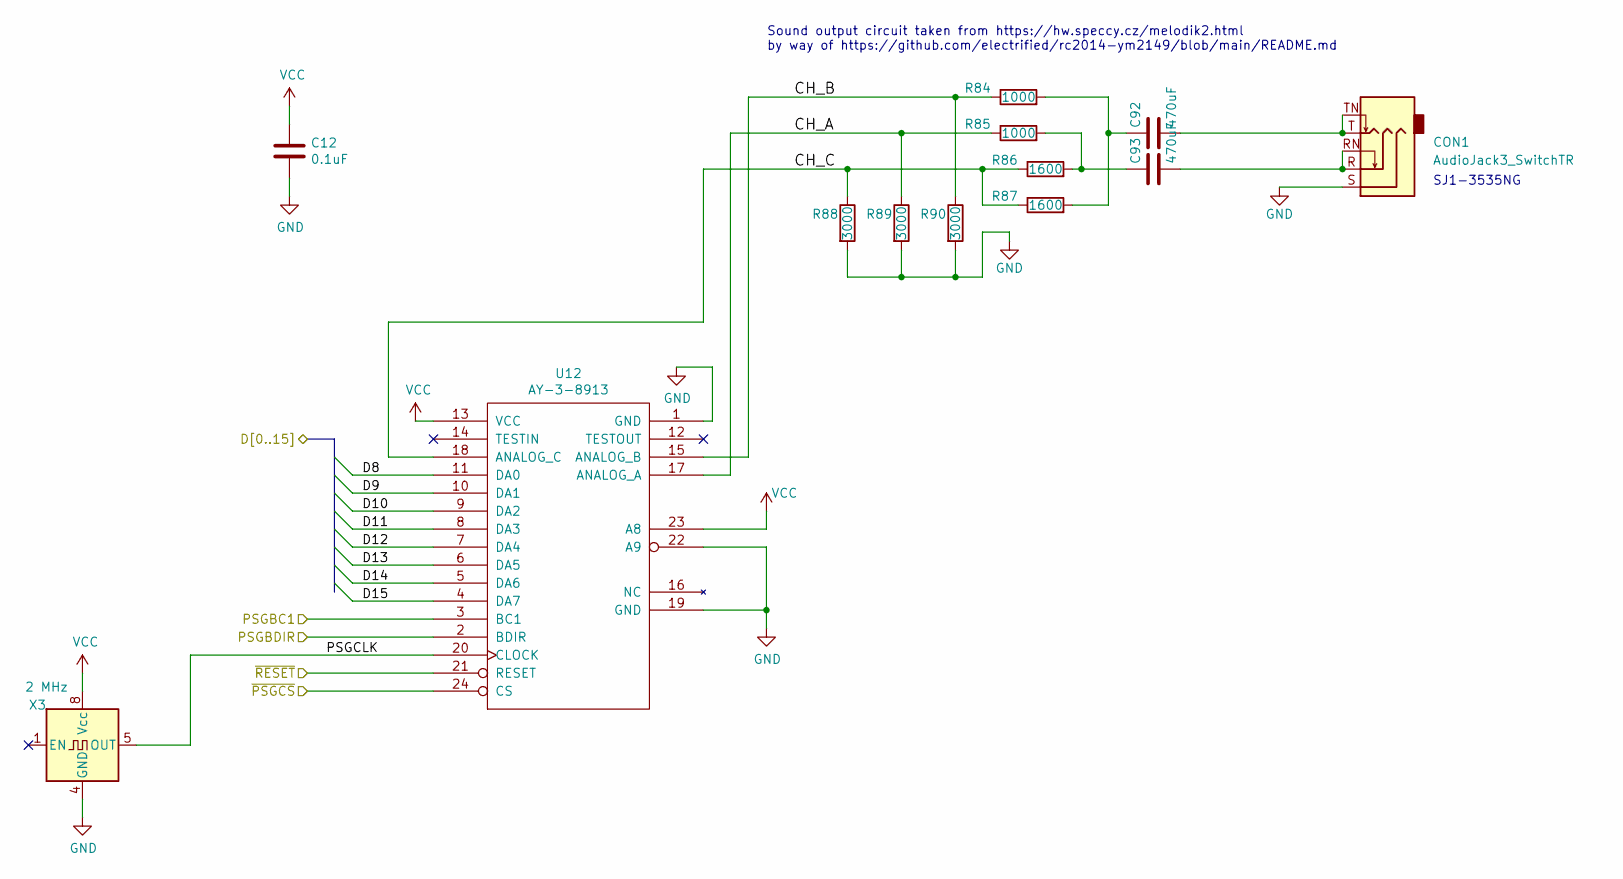
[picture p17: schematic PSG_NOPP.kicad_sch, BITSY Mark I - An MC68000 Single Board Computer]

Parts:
C12: 0.1uF; C_Rect_L7.0mm_W2.0mm_P5.00mm; PartNum00 594-K104K15X7RF5TH5
C92, C93: 470uF; CP_Radial_D6.3mm_P2.50mm; PartNum00 80-ESK477M6R3AE3AA
CON1: AudioJack3_SwitchTR; Jack_3.5mm_CUI_SJ1-3535NG_Horizontal; PartNum00 490-SJ1-3535NG
R84, R85: 1000; R_Axial_DIN0207_L6.3mm_D2.5mm_P7.62mm_Horizontal; PartNum00 603-MFR-25FTE52-1K
R86, R87: 1600; R_Axial_DIN0207_L6.3mm_D2.5mm_P7.62mm_Horizontal; PartNum00 603-MFR-25FTE52-1K6
R88, R89, R90: 3000; R_Axial_DIN0207_L6.3mm_D2.5mm_P7.62mm_Horizontal; PartNum00 603-MFR-25FTE52-3K
U12: AY-3-8913; DIP-24_W15.24mm_Socket_LongPads; PartNum00 AY-3-8913
X3: 2 MHz; Oscillator_DIP-8; PartNum00 774-MXO45HS2C2M0000

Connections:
/CONTROL/PSGBDIR: U12.2 (BDIR); also elsewhere on the board
/D8: U12.11 (DA0); also elsewhere on the board
/D9: U12.10 (DA1); also elsewhere on the board
/D10: U12.9 (DA2); also elsewhere on the board
/D11: U12.8 (DA3); also elsewhere on the board
/D12: U12.7 (DA4); also elsewhere on the board
/D13: U12.6 (DA5); also elsewhere on the board
/D14: U12.5 (DA6); also elsewhere on the board
/D15: U12.4 (DA7); also elsewhere on the board
/PSGBC1: U12.3 (BC1); also elsewhere on the board
/PSG_NOPP/CH_A: R85.1, R89.1, U12.17 (ANALOG_A)
/PSG_NOPP/CH_B: R84.1, R90.1, U12.15 (ANALOG_B)
/PSG_NOPP/CH_C: R86.1, R87.1, R88.1, U12.18 (ANALOG_C)
/PSG_NOPP/PSGCLK: U12.20 (CLOCK), X3.5 (OUT)
/~PSGCS: U12.24 (CS); also elsewhere on the board
/~RESET: U12.21 (RESET); also elsewhere on the board
GND: C12.2, CON1.S, R88.2, R89.2, R90.2, U12.1 (GND), U12.19 (GND), U12.22 (A9), X3.4 (GND); also elsewhere on the board
unnamed: C92.1, R84.2, R87.2
unnamed: C92.2, CON1.T, CON1.TN
unnamed: C93.1, R85.2, R86.2
unnamed: C93.2, CON1.R, CON1.RN
VCC: C12.1, U12.13 (VCC), U12.23 (A8), X3.8 (Vcc); also elsewhere on the board

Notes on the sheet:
SJ1-3535NG
Sound output circuit taken from https://hw.speccy.cz/melodik2.html by way of https://github.com/electrified/rc2014-ym2149/blob/main/README.md

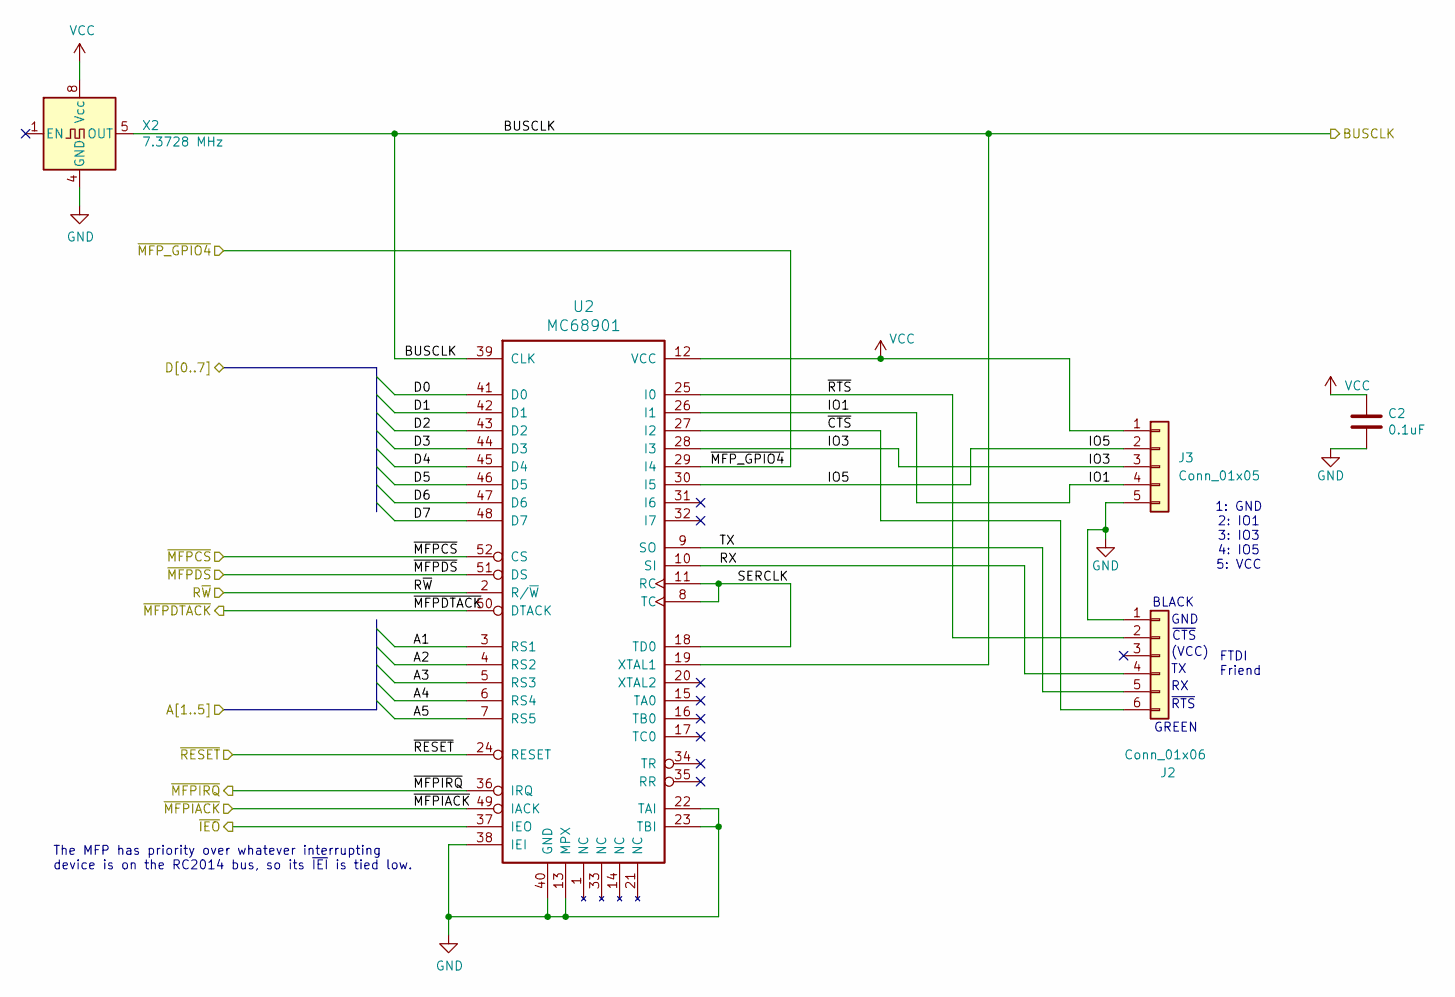
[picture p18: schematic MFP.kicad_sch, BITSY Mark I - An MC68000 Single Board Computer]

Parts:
C2: 0.1uF; C_Rect_L7.0mm_W2.0mm_P5.00mm; PartNum00 594-K104K15X7RF5TH5
J2: Conn_01x06; PinHeader_1x06_P2.54mm_Horizontal; PartNum00 737-PH1RB-06-UA
J3: Conn_01x05; PinHeader_1x05_P2.54mm_Horizontal; PartNum00 737-PH1RB-05-UA
U2: MC68901; PLCC-52_THT-Socket; PartNum00 TS68HC901CFN8B
X2: 7.3728 MHz; Oscillator_DIP-8; PartNum00 774-MXO45HS-3C-7.3

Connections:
/A1: U2.3 (RS1); also elsewhere on the board
/A2: U2.4 (RS2); also elsewhere on the board
/A3: U2.5 (RS3); also elsewhere on the board
/A4: U2.6 (RS4); also elsewhere on the board
/A5: U2.7 (RS5); also elsewhere on the board
/BUSCLK: U2.19 (XTAL1), U2.39 (CLK), X2.5 (OUT); also elsewhere on the board
/D0: U2.41 (D0); also elsewhere on the board
/D1: U2.42 (D1); also elsewhere on the board
/D2: U2.43 (D2); also elsewhere on the board
/D3: U2.44 (D3); also elsewhere on the board
/D4: U2.45 (D4); also elsewhere on the board
/D5: U2.46 (D5); also elsewhere on the board
/D6: U2.47 (D6); also elsewhere on the board
/D7: U2.48 (D7); also elsewhere on the board
/MFP/IO1: J3.4, U2.26 (I1)
/MFP/IO3: J3.3, U2.28 (I3)
/MFP/IO5: J3.2, U2.30 (I5)
/MFP/RX: J2.4, U2.10 (SI)
/MFP/SERCLK: U2.8 (TC), U2.11 (RC), U2.18 (TD0)
/MFP/TX: J2.5, U2.9 (SO)
/MFP/~CTS: J2.6, U2.27 (I2)
/MFP/~RTS: J2.2, U2.25 (I0)
/R~W: U2.2 (R/~W); also elsewhere on the board
/~IEO: U2.37 (IEO); also elsewhere on the board
/~LDS: U2.51 (DS); also elsewhere on the board
/~MFPCS: U2.52 (CS); also elsewhere on the board
/~MFPDTACK: U2.50 (DTACK); also elsewhere on the board
/~MFPIACK: U2.49 (IACK); also elsewhere on the board
/~MFPIRQ: U2.36 (IRQ); also elsewhere on the board
/~MFP_GPIO4: U2.29 (I4); also elsewhere on the board
/~RESET: U2.24 (RESET); also elsewhere on the board
GND: C2.2, J2.1, J3.5, U2.13 (MPX), U2.22 (TAI), U2.23 (TBI), U2.38 (IEI), U2.40 (GND), X2.4 (GND); also elsewhere on the board
VCC: C2.1, J3.1, U2.12 (VCC), X2.8 (Vcc); also elsewhere on the board

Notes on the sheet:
(VCC)
FTDI Friend
BLACK
~{CTS}
~{RTS}
GND
GREEN
1: GND 2: IO1 3: IO3 4: IO5 5: VCC
The MFP has priority over whatever interrupting device is on the RC2014 bus, so its ~{IEI} is tied low.

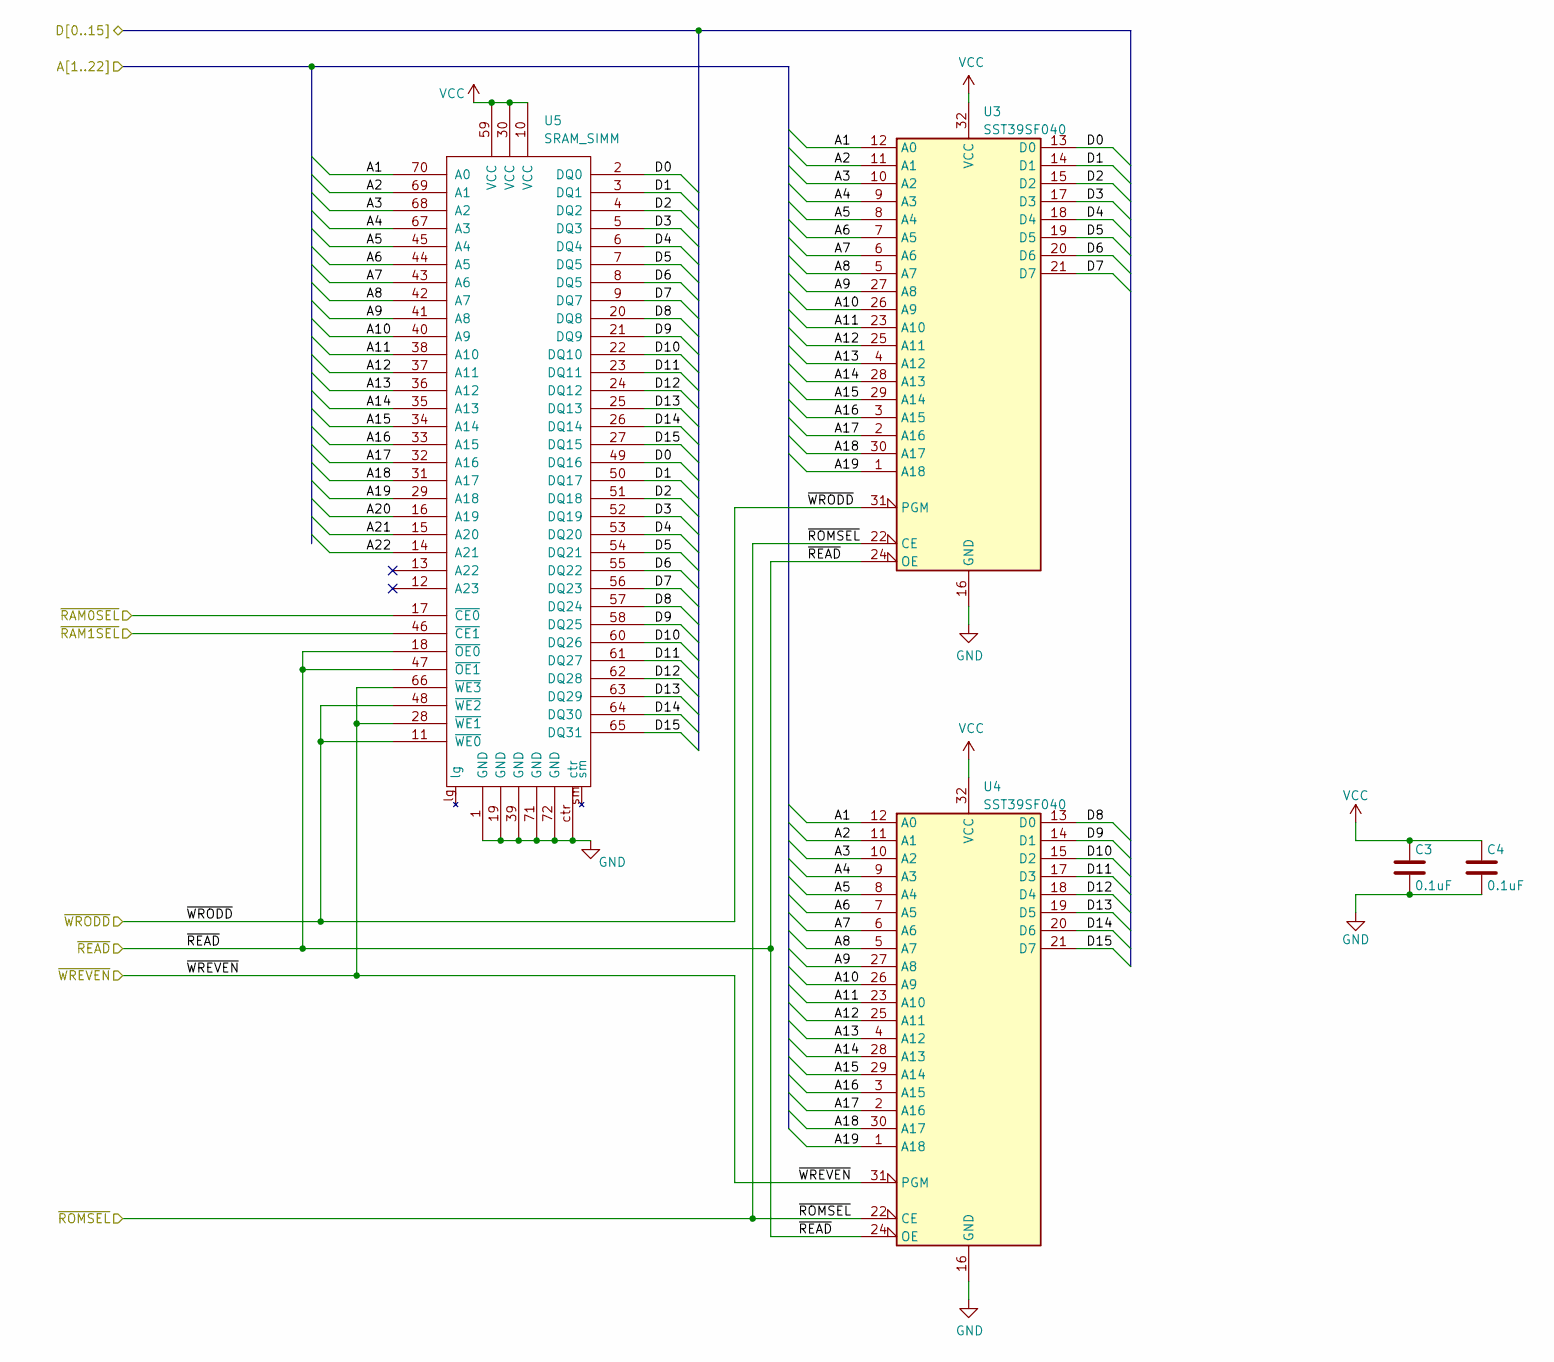
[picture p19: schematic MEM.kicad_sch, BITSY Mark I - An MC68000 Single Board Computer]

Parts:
C3, C4: 0.1uF; C_Rect_L7.0mm_W2.0mm_P5.00mm; PartNum00 594-K104K15X7RF5TH5
U3, U4: SST39SF040; PLCC-32_THT-Socket; PartNum00 579-39SF040554CNHET
U5: SRAM_SIMM; DRAM-72-2021; PartNum00 571-5822021-4

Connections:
/A1: U3.12 (A0), U4.12 (A0), U5.70 (A0); also elsewhere on the board
/A2: U3.11 (A1), U4.11 (A1), U5.69 (A1); also elsewhere on the board
/A3: U3.10 (A2), U4.10 (A2), U5.68 (A2); also elsewhere on the board
/A4: U3.9 (A3), U4.9 (A3), U5.67 (A3); also elsewhere on the board
/A5: U3.8 (A4), U4.8 (A4), U5.45 (A4); also elsewhere on the board
/A6: U3.7 (A5), U4.7 (A5), U5.44 (A5); also elsewhere on the board
/A7: U3.6 (A6), U4.6 (A6), U5.43 (A6); also elsewhere on the board
/A8: U3.5 (A7), U4.5 (A7), U5.42 (A7); also elsewhere on the board
/A9: U3.27 (A8), U4.27 (A8), U5.41 (A8); also elsewhere on the board
/A10: U3.26 (A9), U4.26 (A9), U5.40 (A9); also elsewhere on the board
/A11: U3.23 (A10), U4.23 (A10), U5.38 (A10); also elsewhere on the board
/A12: U3.25 (A11), U4.25 (A11), U5.37 (A11); also elsewhere on the board
/A13: U3.4 (A12), U4.4 (A12), U5.36 (A12); also elsewhere on the board
/A14: U3.28 (A13), U4.28 (A13), U5.35 (A13); also elsewhere on the board
/A15: U3.29 (A14), U4.29 (A14), U5.34 (A14); also elsewhere on the board
/A16: U3.3 (A15), U4.3 (A15), U5.33 (A15); also elsewhere on the board
/A17: U3.2 (A16), U4.2 (A16), U5.32 (A16); also elsewhere on the board
/A18: U3.30 (A17), U4.30 (A17), U5.31 (A17); also elsewhere on the board
/A19: U3.1 (A18), U4.1 (A18), U5.29 (A18); also elsewhere on the board
/A20: U5.16 (A19); also elsewhere on the board
/A21: U5.15 (A20); also elsewhere on the board
/A22: U5.14 (A21); also elsewhere on the board
/D0: U3.13 (D0), U5.2 (DQ0), U5.49 (DQ16); also elsewhere on the board
/D1: U3.14 (D1), U5.3 (DQ1), U5.50 (DQ17); also elsewhere on the board
/D2: U3.15 (D2), U5.4 (DQ2), U5.51 (DQ18); also elsewhere on the board
/D3: U3.17 (D3), U5.5 (DQ3), U5.52 (DQ19); also elsewhere on the board
/D4: U3.18 (D4), U5.6 (DQ4), U5.53 (DQ20); also elsewhere on the board
/D5: U3.19 (D5), U5.7 (DQ5), U5.54 (DQ21); also elsewhere on the board
/D6: U3.20 (D6), U5.8 (DQ5), U5.55 (DQ22); also elsewhere on the board
/D7: U3.21 (D7), U5.9 (DQ7), U5.56 (DQ23); also elsewhere on the board
/D8: U4.13 (D0), U5.20 (DQ8), U5.57 (DQ24); also elsewhere on the board
/D9: U4.14 (D1), U5.21 (DQ9), U5.58 (DQ25); also elsewhere on the board
/D10: U4.15 (D2), U5.22 (DQ10), U5.60 (DQ26); also elsewhere on the board
/D11: U4.17 (D3), U5.23 (DQ11), U5.61 (DQ27); also elsewhere on the board
/D12: U4.18 (D4), U5.24 (DQ12), U5.62 (DQ28); also elsewhere on the board
/D13: U4.19 (D5), U5.25 (DQ13), U5.63 (DQ29); also elsewhere on the board
/D14: U4.20 (D6), U5.26 (DQ14), U5.64 (DQ30); also elsewhere on the board
/D15: U4.21 (D7), U5.27 (DQ15), U5.65 (DQ31); also elsewhere on the board
/~RAM0CS: U5.17 (~CE0); also elsewhere on the board
/~RAM1CS: U5.46 (~CE1); also elsewhere on the board
/~READ: U3.24 (OE), U4.24 (OE), U5.18 (~OE0), U5.47 (~OE1); also elsewhere on the board
/~ROMCS: U3.22 (CE), U4.22 (CE); also elsewhere on the board
/~WREVEN: U4.31 (PGM), U5.28 (~WE1), U5.66 (~WE3); also elsewhere on the board
/~WRODD: U3.31 (PGM), U5.11 (~WE0), U5.48 (~WE2); also elsewhere on the board
GND: C3.2, C4.2, U3.16 (GND), U4.16 (GND), U5.1 (GND), U5.19 (GND), U5.39 (GND), U5.71 (GND), U5.72 (GND), U5.ctr; also elsewhere on the board
VCC: C3.1, C4.1, U3.32 (VCC), U4.32 (VCC), U5.10 (VCC), U5.30 (VCC), U5.59 (VCC); also elsewhere on the board

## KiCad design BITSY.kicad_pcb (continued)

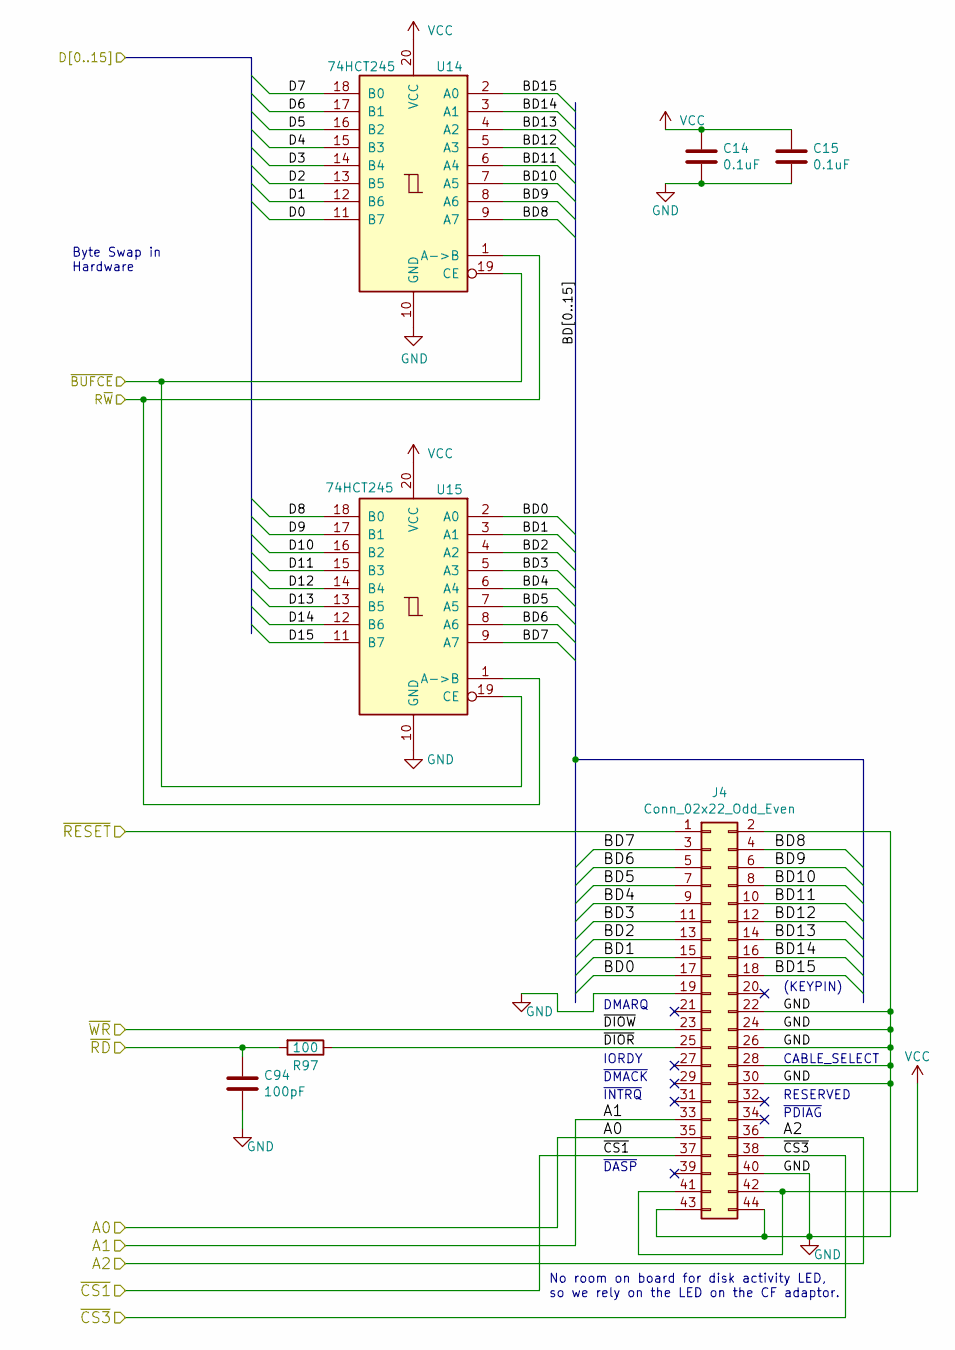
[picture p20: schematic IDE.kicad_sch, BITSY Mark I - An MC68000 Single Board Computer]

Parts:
C14, C15: 0.1uF; C_Rect_L7.0mm_W2.0mm_P5.00mm; PartNum00 594-K104K15X7RF5TH5
C94: 100pF; C_Rect_L7.0mm_W2.0mm_P5.00mm; PartNum00 594-K101J15C0GF5TH5
J4: Conn_02x22_Odd_Even; PAD_2X22
R97: 100; R_Axial_DIN0207_L6.3mm_D2.5mm_P7.62mm_Horizontal; PartNum00 603-MFR-25FBF52-100R
U14, U15: 74HCT245; DIP-20_W7.62mm_Socket; PartNum00 595-SN74HCT245N

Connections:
/A2: J4.35; also elsewhere on the board
/A3: J4.33; also elsewhere on the board
/A4: J4.36; also elsewhere on the board
/D0: U14.11 (B7); also elsewhere on the board
/D1: U14.12 (B6); also elsewhere on the board
/D2: U14.13 (B5); also elsewhere on the board
/D3: U14.14 (B4); also elsewhere on the board
/D4: U14.15 (B3); also elsewhere on the board
/D5: U14.16 (B2); also elsewhere on the board
/D6: U14.17 (B1); also elsewhere on the board
/D7: U14.18 (B0); also elsewhere on the board
/D8: U15.18 (B0); also elsewhere on the board
/D9: U15.17 (B1); also elsewhere on the board
/D10: U15.16 (B2); also elsewhere on the board
/D11: U15.15 (B3); also elsewhere on the board
/D12: U15.14 (B4); also elsewhere on the board
/D13: U15.13 (B5); also elsewhere on the board
/D14: U15.12 (B6); also elsewhere on the board
/D15: U15.11 (B7); also elsewhere on the board
/IDE/BD0: J4.17, U15.2 (A0)
/IDE/BD1: J4.15, U15.3 (A1)
/IDE/BD2: J4.13, U15.4 (A2)
/IDE/BD3: J4.11, U15.5 (A3)
/IDE/BD4: J4.9, U15.6 (A4)
/IDE/BD5: J4.7, U15.7 (A5)
/IDE/BD6: J4.5, U15.8 (A6)
/IDE/BD7: J4.3, U15.9 (A7)
/IDE/BD8: J4.4, U14.9 (A7)
/IDE/BD9: J4.6, U14.8 (A6)
/IDE/BD10: J4.8, U14.7 (A5)
/IDE/BD11: J4.10, U14.6 (A4)
/IDE/BD12: J4.12, U14.5 (A3)
/IDE/BD13: J4.14, U14.4 (A2)
/IDE/BD14: J4.16, U14.3 (A1)
/IDE/BD15: J4.18, U14.2 (A0)
/IDE/~DIOR: J4.25, R97.1
/R~W: U14.1 (A->B), U15.1 (A->B); also elsewhere on the board
/~DIOR: C94.1, R97.2; also elsewhere on the board
/~DIOW: J4.23; also elsewhere on the board
/~ICECS: U14.19 (CE), U15.19 (CE); also elsewhere on the board
/~IDECS1: J4.37; also elsewhere on the board
/~IDECS3: J4.38; also elsewhere on the board
/~RESET: J4.1; also elsewhere on the board
GND: C14.2, C15.2, C94.2, J4.2, J4.19, J4.22, J4.24, J4.26, J4.28, J4.30, J4.40, J4.43, J4.44, U14.10 (GND), U15.10 (GND); also elsewhere on the board
VCC: C14.1, C15.1, J4.41, J4.42, U14.20 (VCC), U15.20 (VCC); also elsewhere on the board

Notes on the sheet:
RESERVED
~{INTRQ}
No room on board for disk activity LED, so we rely on the LED on the CF adaptor.
Byte Swap in Hardware
IORDY
(KEYPIN)
~{PDIAG}
~{DASP}
DMARQ
~{DMACK}
CABLE_SELECT

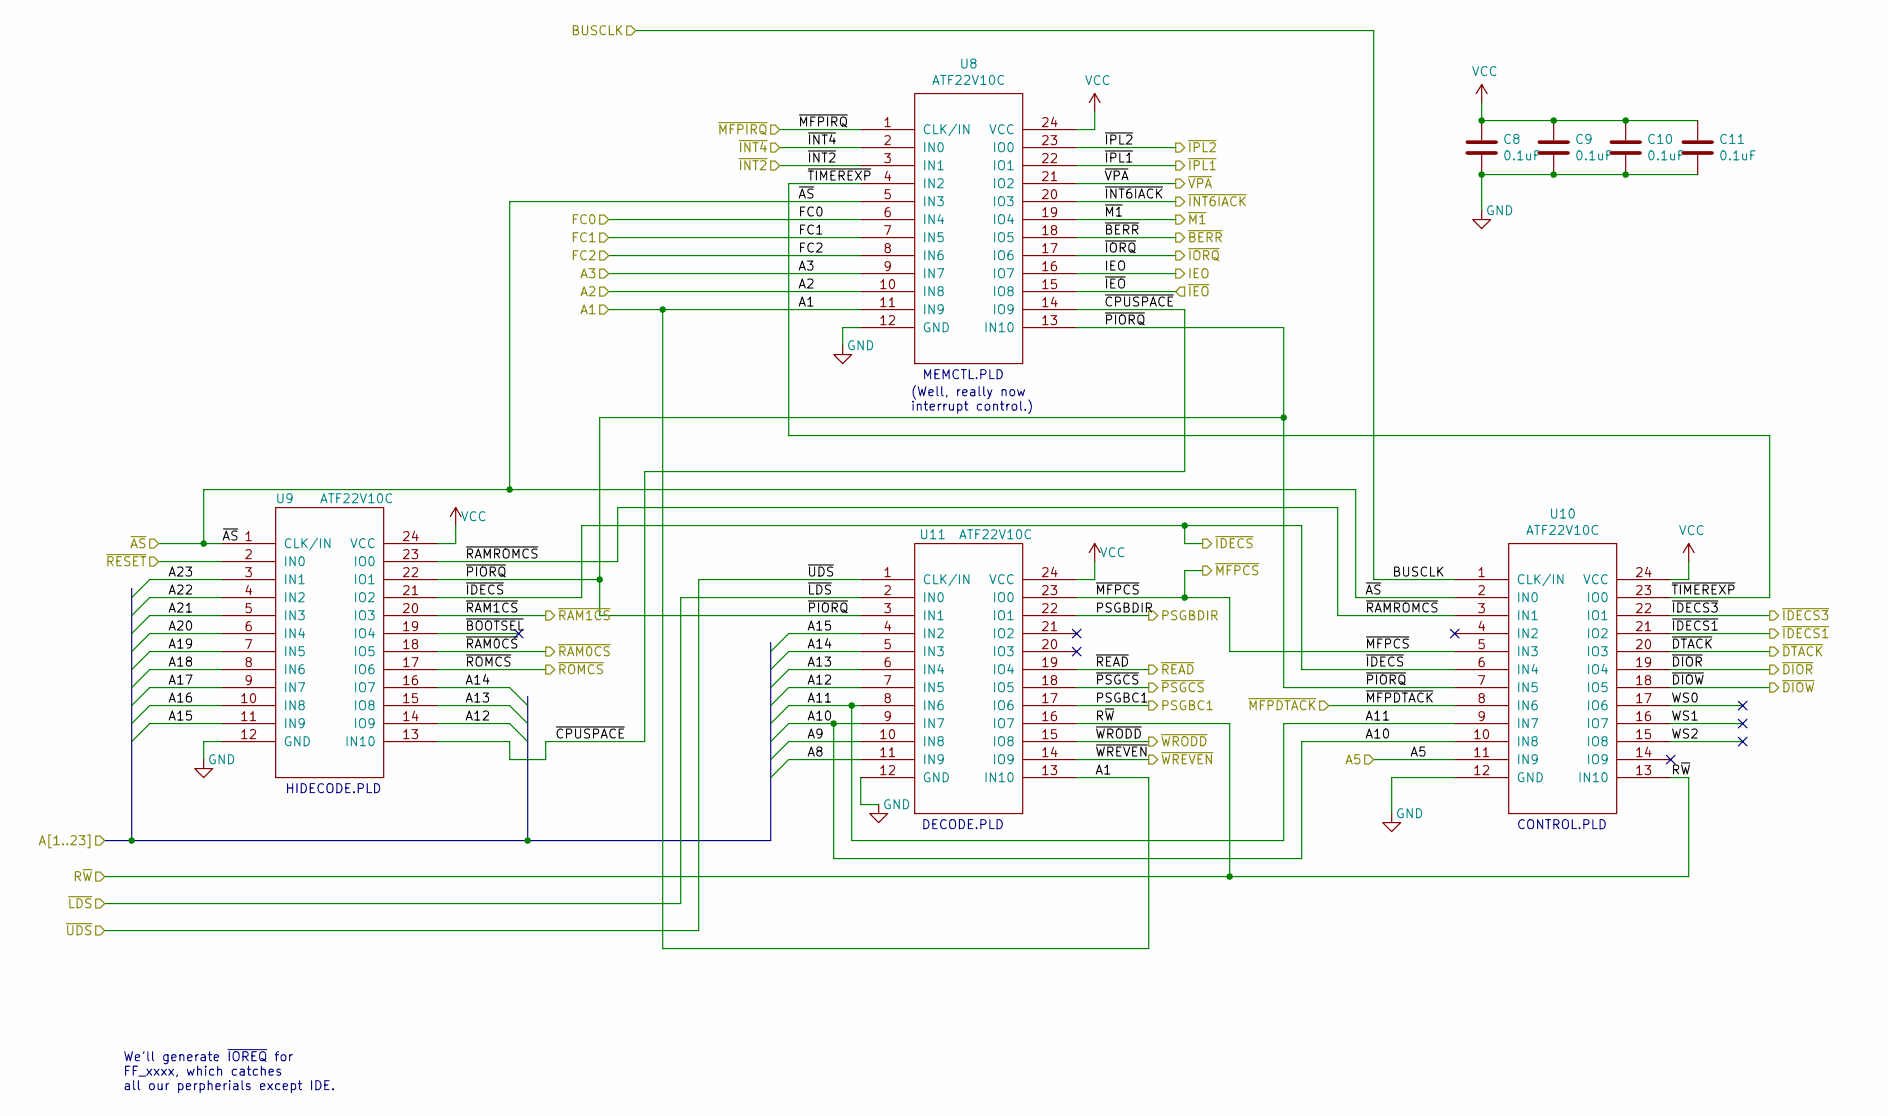
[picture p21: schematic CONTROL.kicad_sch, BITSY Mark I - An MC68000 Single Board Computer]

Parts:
C8, C9, C10, C11: 0.1uF; C_Rect_L7.0mm_W2.0mm_P5.00mm; PartNum00 594-K104K15X7RF5TH5
U8, U9, U10, U11: ATF22V10C; DIP-24_W7.62mm_Socket; PartNum00 556-AF22V10C15PU

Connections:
/A1: U8.11 (IN9), U11.13 (IN10); also elsewhere on the board
/A2: U8.10 (IN8); also elsewhere on the board
/A3: U8.9 (IN7); also elsewhere on the board
/A5: U10.11 (IN9); also elsewhere on the board
/A8: U11.11 (IN9); also elsewhere on the board
/A9: U11.10 (IN8); also elsewhere on the board
/A10: U10.10 (IN8), U11.9 (IN7); also elsewhere on the board
/A11: U10.9 (IN7), U11.8 (IN6); also elsewhere on the board
/A12: U9.14 (IO9), U11.7 (IN5); also elsewhere on the board
/A13: U9.15 (IO8), U11.6 (IN4); also elsewhere on the board
/A14: U9.16 (IO7), U11.5 (IN3); also elsewhere on the board
/A15: U9.11 (IN9), U11.4 (IN2); also elsewhere on the board
/A16: U9.10 (IN8); also elsewhere on the board
/A17: U9.9 (IN7); also elsewhere on the board
/A18: U9.8 (IN6); also elsewhere on the board
/A19: U9.7 (IN5); also elsewhere on the board
/A20: U9.6 (IN4); also elsewhere on the board
/A21: U9.5 (IN3); also elsewhere on the board
/A22: U9.4 (IN2); also elsewhere on the board
/A23: U9.3 (IN1); also elsewhere on the board
/BUSCLK: U10.1 (CLK/IN); also elsewhere on the board
/CONTROL/PSGBDIR: U11.22 (IO1); also elsewhere on the board
/CONTROL/WS0: U10.17 (IO6)
/CONTROL/WS1: U10.16 (IO7)
/CONTROL/WS2: U10.15 (IO8)
/CONTROL/~BOOTSEL: U9.19 (IO4)
/CONTROL/~CPUSPACE: U8.14 (IO9), U9.13 (IN10)
/CONTROL/~PIORQ: U8.13 (IN10), U9.22 (IO1), U10.7 (IN5), U11.3 (IN1)
/CONTROL/~RAMROMCS: U9.23 (IO0), U10.3 (IN1)
/CONTROL/~TIMEREXP: U8.4 (IN2), U10.23 (IO0)
/FC0: U8.6 (IN4); also elsewhere on the board
/FC1: U8.7 (IN5); also elsewhere on the board
/FC2: U8.8 (IN6); also elsewhere on the board
/IEO: U8.16 (IO7); also elsewhere on the board
/PSGBC1: U11.17 (IO6); also elsewhere on the board
/R~W: U10.13 (IN10), U11.16 (IO7); also elsewhere on the board
/~AS: U8.5 (IN3), U9.1 (CLK/IN), U10.2 (IN0); also elsewhere on the board
/~BERR: U8.18 (IO5); also elsewhere on the board
/~DIOR: U10.19 (IO4); also elsewhere on the board
/~DIOW: U10.18 (IO5); also elsewhere on the board
/~DTACK: U10.20 (IO3); also elsewhere on the board
/~ICECS: U9.21 (IO2), U10.6 (IN4); also elsewhere on the board
/~IDECS1: U10.21 (IO2); also elsewhere on the board
/~IDECS3: U10.22 (IO1); also elsewhere on the board
/~IEO: U8.15 (IO8); also elsewhere on the board
/~INT2: U8.3 (IN1); also elsewhere on the board
/~INT4: U8.2 (IN0); also elsewhere on the board
/~IORQ: U8.17 (IO6); also elsewhere on the board
/~IPL1: U8.22 (IO1); also elsewhere on the board
/~IPL2: U8.23 (IO0); also elsewhere on the board
/~LDS: U11.2 (IN0); also elsewhere on the board
/~M1: U8.19 (IO4); also elsewhere on the board
/~MFPCS: U10.5 (IN3), U11.23 (IO0); also elsewhere on the board
/~MFPDTACK: U10.8 (IN6); also elsewhere on the board
/~MFPIACK: U8.20 (IO3); also elsewhere on the board
/~MFPIRQ: U8.1 (CLK/IN); also elsewhere on the board
/~PSGCS: U11.18 (IO5); also elsewhere on the board
/~RAM0CS: U9.18 (IO5); also elsewhere on the board
/~RAM1CS: U9.20 (IO3); also elsewhere on the board
/~READ: U11.19 (IO4); also elsewhere on the board
/~RESET: U9.2 (IN0); also elsewhere on the board
/~ROMCS: U9.17 (IO6); also elsewhere on the board
/~UDS: U11.1 (CLK/IN); also elsewhere on the board
/~VPA: U8.21 (IO2); also elsewhere on the board
/~WREVEN: U11.14 (IO9); also elsewhere on the board
/~WRODD: U11.15 (IO8); also elsewhere on the board
GND: C8.2, C9.2, C10.2, C11.2, U8.12 (GND), U9.12 (GND), U10.12 (GND), U11.12 (GND); also elsewhere on the board
VCC: C8.1, C9.1, C10.1, C11.1, U8.24 (VCC), U9.24 (VCC), U10.24 (VCC), U11.24 (VCC); also elsewhere on the board

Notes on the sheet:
HIDECODE.PLD
CONTROL.PLD
MEMCTL.PLD
We’ll generate ~{IOREQ} for FF_xxxx, which catches all our perpherials except IDE.
DECODE.PLD
(Well, really now interrupt control.)

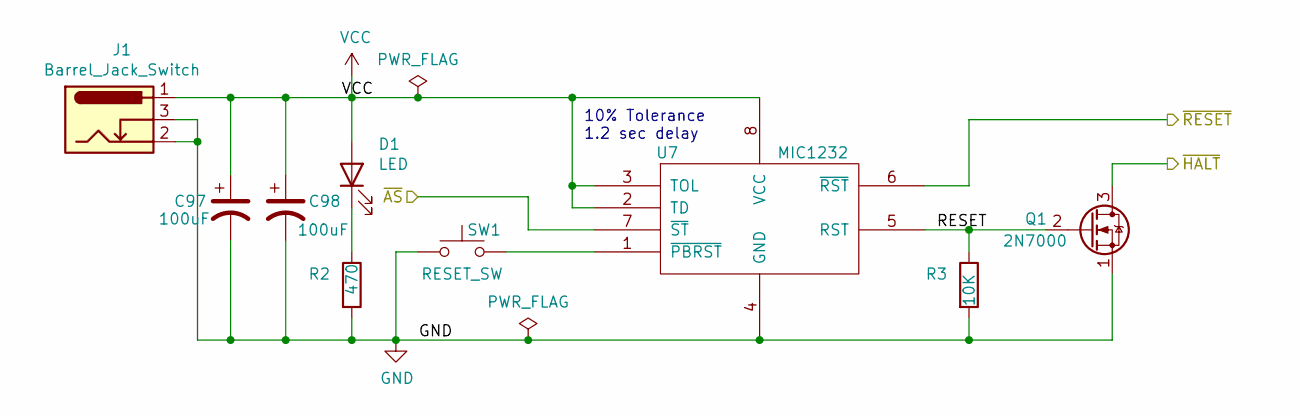
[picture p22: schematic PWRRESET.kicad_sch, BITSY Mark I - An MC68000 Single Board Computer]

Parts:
C97, C98: 100uF; CP_Radial_Tantal_D4.5mm_P2.50mm; PartNum00 667-ECA-1CM101I
D1: LED; LED_D5.0mm; PartNum00 859-LTL-307GLC
J1: Barrel_Jack_Switch; BarrelJack_Horizontal; PartNum00 490-PJ-002A
Q1: 2N7000; TO-92_HandSolder; PartNum00 512-2N7000
R2: 470; R_Axial_DIN0207_L6.3mm_D2.5mm_P7.62mm_Horizontal; PartNum00 603-MFR-25FTE52-470R
R3: 10K; R_Axial_DIN0207_L6.3mm_D2.5mm_P7.62mm_Horizontal; PartNum00 603-MFR-25FTE52-10K
SW1: RESET_SW; SW_PUSH_6mm; PartNum00 179-TS026655BK160LCR
U7: MIC1232; DIP-8_W7.62mm_Socket_LongPads; PartNum00 998-MIC1232NY

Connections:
/PWRRESET/RESET: Q1.2 (G), R3.1, U7.5 (RST)
/~AS: U7.7 (~ST); also elsewhere on the board
/~HALT: Q1.3 (D); also elsewhere on the board
/~RESET: U7.6 (~RST); also elsewhere on the board
GND: C97.2, C98.2, J1.2, J1.3, Q1.1 (S), R2.2, R3.2, SW1.1, U7.4 (GND); also elsewhere on the board
unnamed: D1.1 (K), R2.1
unnamed: SW1.2, U7.1 (~PBRST)
VCC: C97.1, C98.1, D1.2 (A), J1.1, U7.2 (TD), U7.3 (TOL), U7.8 (VCC); also elsewhere on the board

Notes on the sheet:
10% Tolerance 1.2 sec delay

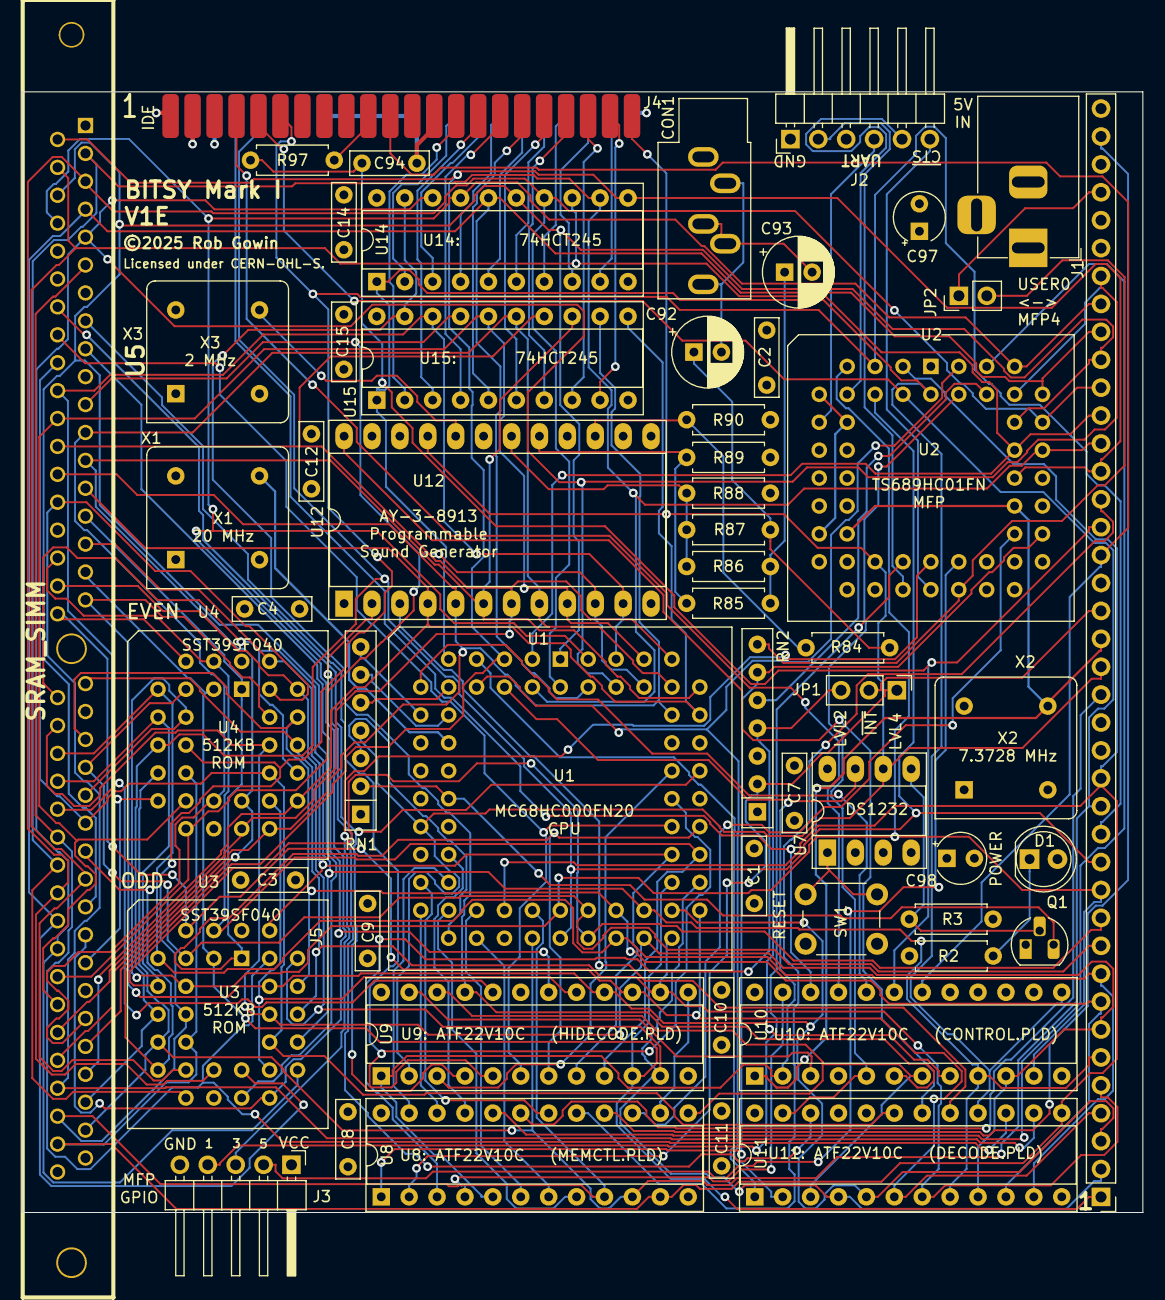
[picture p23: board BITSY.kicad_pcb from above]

Board: 4 copper layers, 102.0 x 102.0 mm, 56 parts (0 on the bottom side), 128 nets.

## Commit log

2025-06-17 Initial commit.
    [BITSY.kicad_pcb, BITSY.kicad_sch, CONTROL.kicad_sch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]
2025-06-17 Remove interactive BOM link for now.
2025-08-10 Fix issue with interrupt acknowledge.
    Also, add proper support for using 68K interrupt level 2.
2025-08-15 V1C version of BITSY that uses an SRAM SIMM for memory.
    This version sent to JLCPCB on 08/15/2025.
    [BITSY.kicad_pcb, BITSY.kicad_sch, CONTROL.kicad_sch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]
2025-08-16 Add part numbers.
    No board change.
    [MEM.kicad_sch]
2025-09-25 Add two extra SIMM address lines.
    [BITSY.kicad_pcb, BITSY.kicad_sch, MEM.kicad_sch]
2025-10-02 Update version info
    [BITSY.kicad_pcb]
2025-10-09 Update part numbers.
    [BITSY.kicad_sch, CONTROL.kicad_sch, IDE.kicad_sch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]
2025-11-10 Create V1E version.
    Adds extra address line to SIMM for 16 MB support.
    [BITSY.kicad_pcb, BITSY.kicad_sch, CONTROL.kicad_sch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]
2025-11-19 MEMCTL: Assert INT6IACK only for level 6 interrupts.
    Thanks to Bill Bond for the bug report.
2025-11-20 Add routed PCB for V1E.
    [BITSY.kicad_pcb]
2025-11-29 Add 1 MB SRAM SIMM design.
    [SRAM_SIMM_1MB.kicad_pcb, SRAM_SIMM_1MB.kicad_sch]
2025-11-29 Add V1E Gerber file.

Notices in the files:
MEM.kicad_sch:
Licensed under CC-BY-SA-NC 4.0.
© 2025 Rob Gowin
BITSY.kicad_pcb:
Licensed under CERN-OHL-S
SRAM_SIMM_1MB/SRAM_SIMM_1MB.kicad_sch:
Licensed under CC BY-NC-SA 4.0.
